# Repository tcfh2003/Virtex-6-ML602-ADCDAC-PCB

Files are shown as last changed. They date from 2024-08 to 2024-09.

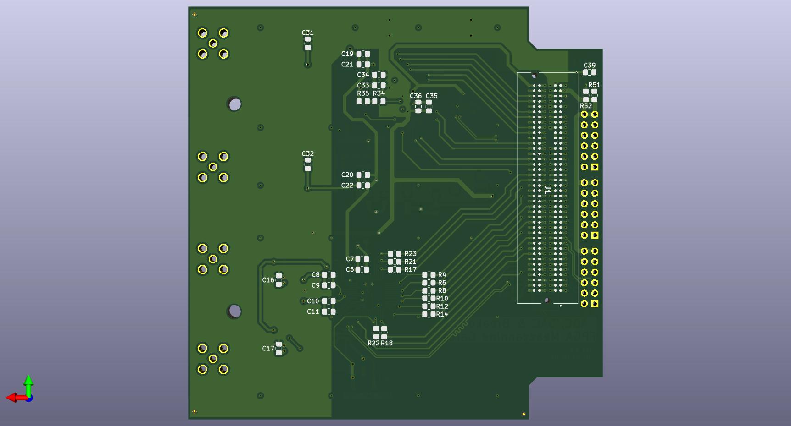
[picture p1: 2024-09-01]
Schematic_and_PCB_Photos/rev1.1/PCB_3DView_BOTTOM_noComponents.png

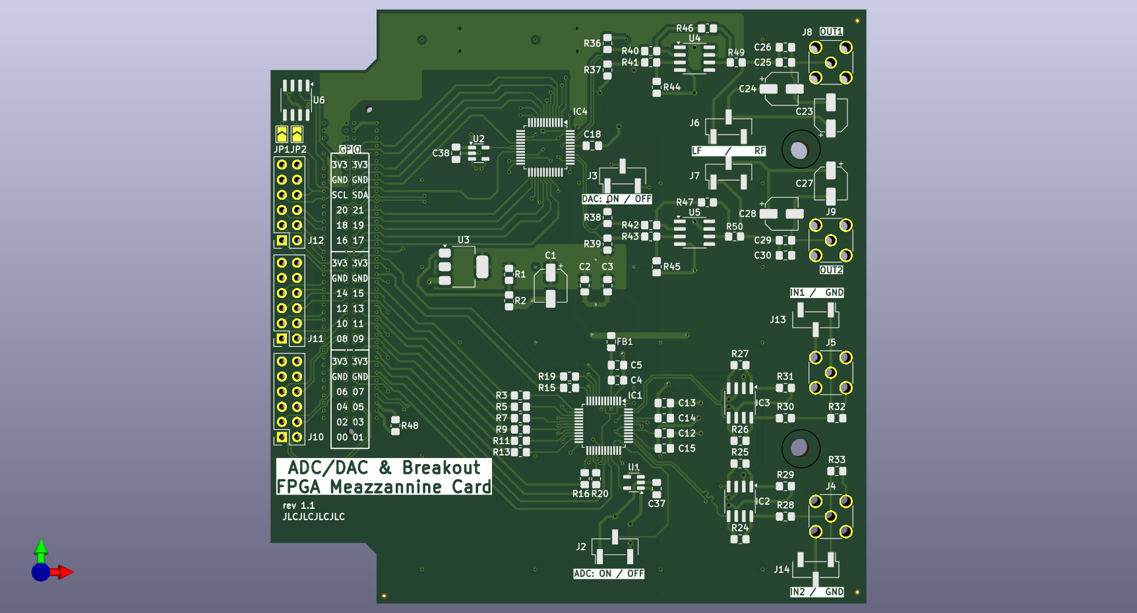
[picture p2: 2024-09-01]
Schematic_and_PCB_Photos/rev1.1/PCB_3DView_TOP_noComponents.png

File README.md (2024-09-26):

# ADC/DAC FPGA Mezannine Card utilizing VITA 57.1 compliant LPC connector.

ADC used is ADC10D040CIVS and has two 10-bit 40 MSa/s channels. DAC used is DAC5652 and has two 10-bit 200 MSa/s channels. 

You can view the PCB online by using https://kicanvas.org (made by theacodes, project github link https://github.com/theacodes/kicanvas.git), and providing the link for the .pro file in this repo.

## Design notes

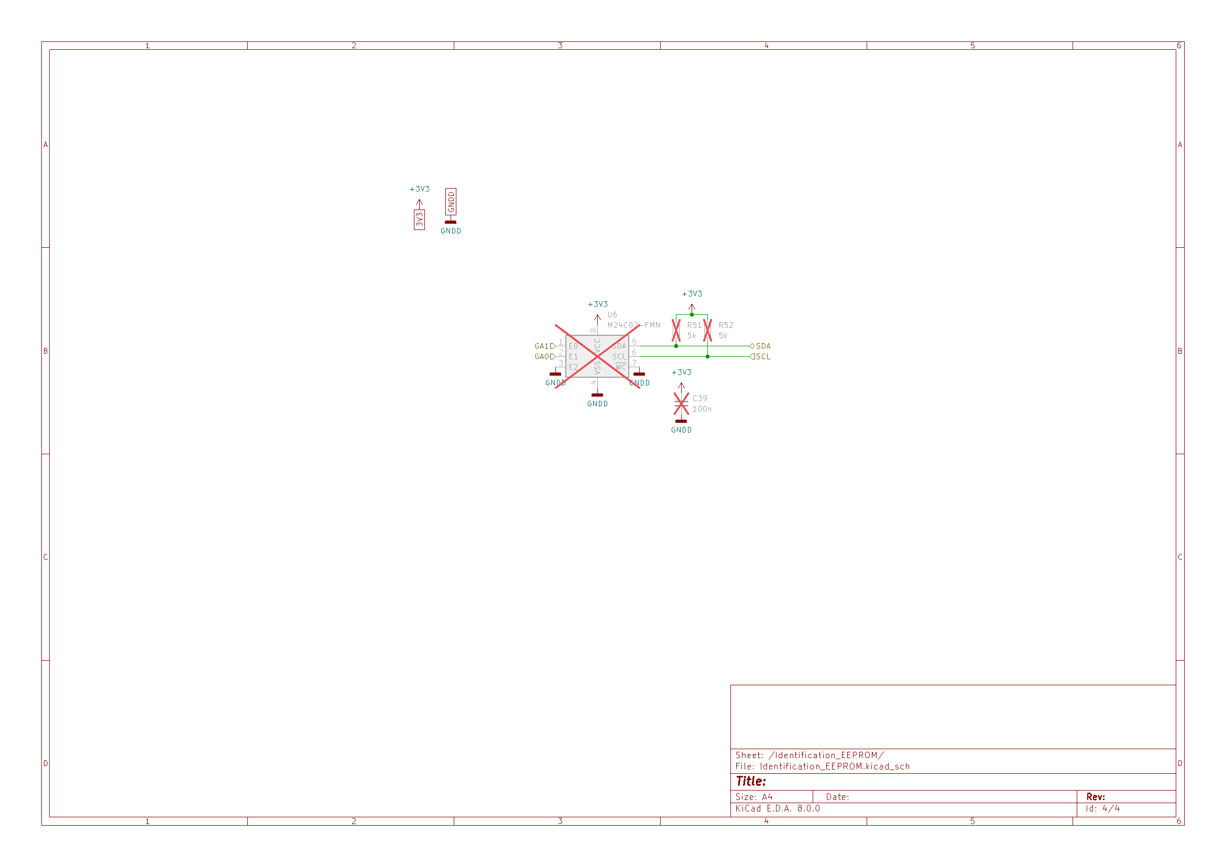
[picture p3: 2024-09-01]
Schematic_and_PCB_Photos/rev1.1/ML605_LPC_Board_wADC_DAC conv 4.png

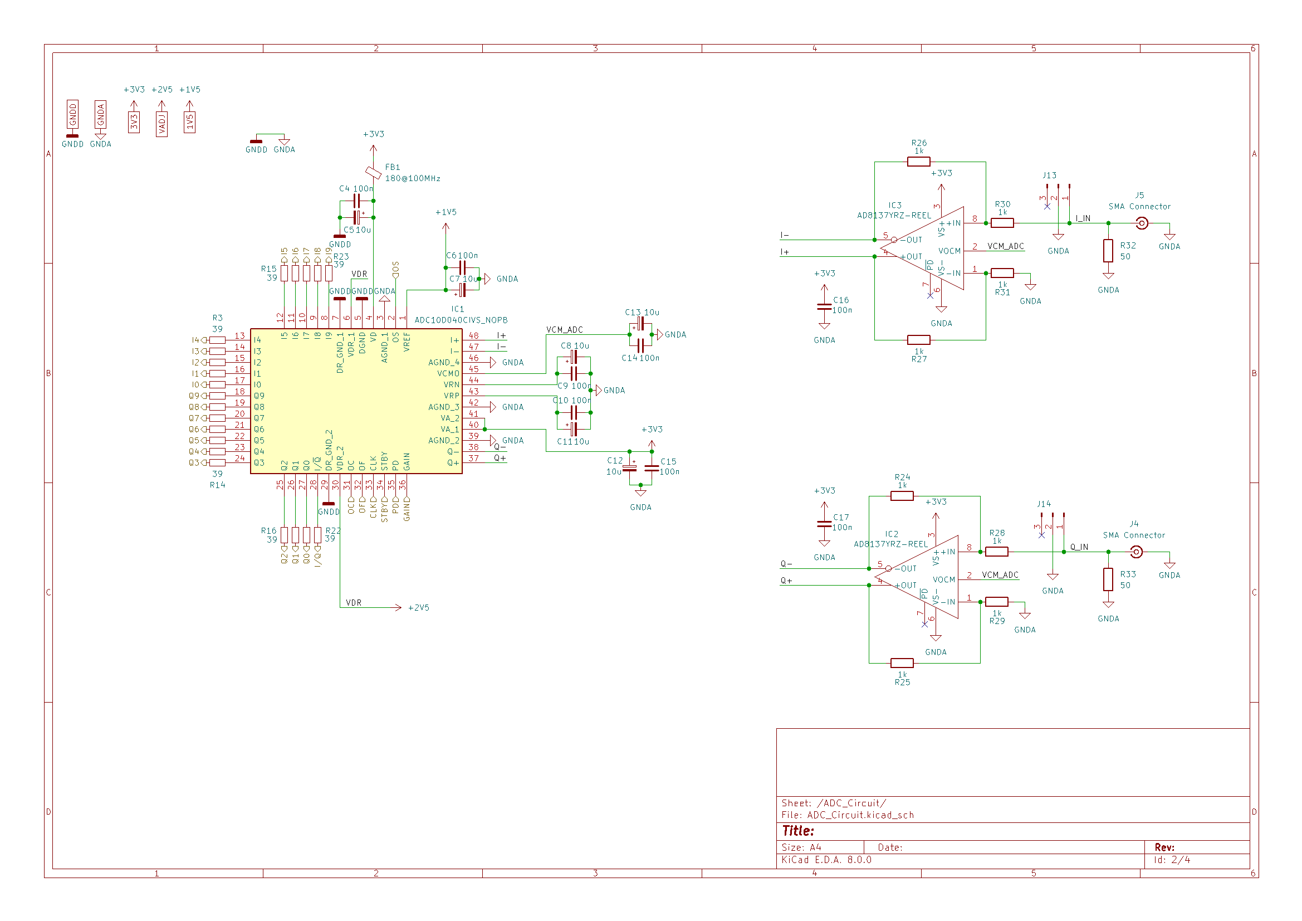
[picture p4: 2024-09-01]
Schematic_and_PCB_Photos/rev1.1/ML605_LPC_Board_wADC_DAC conv 2.png

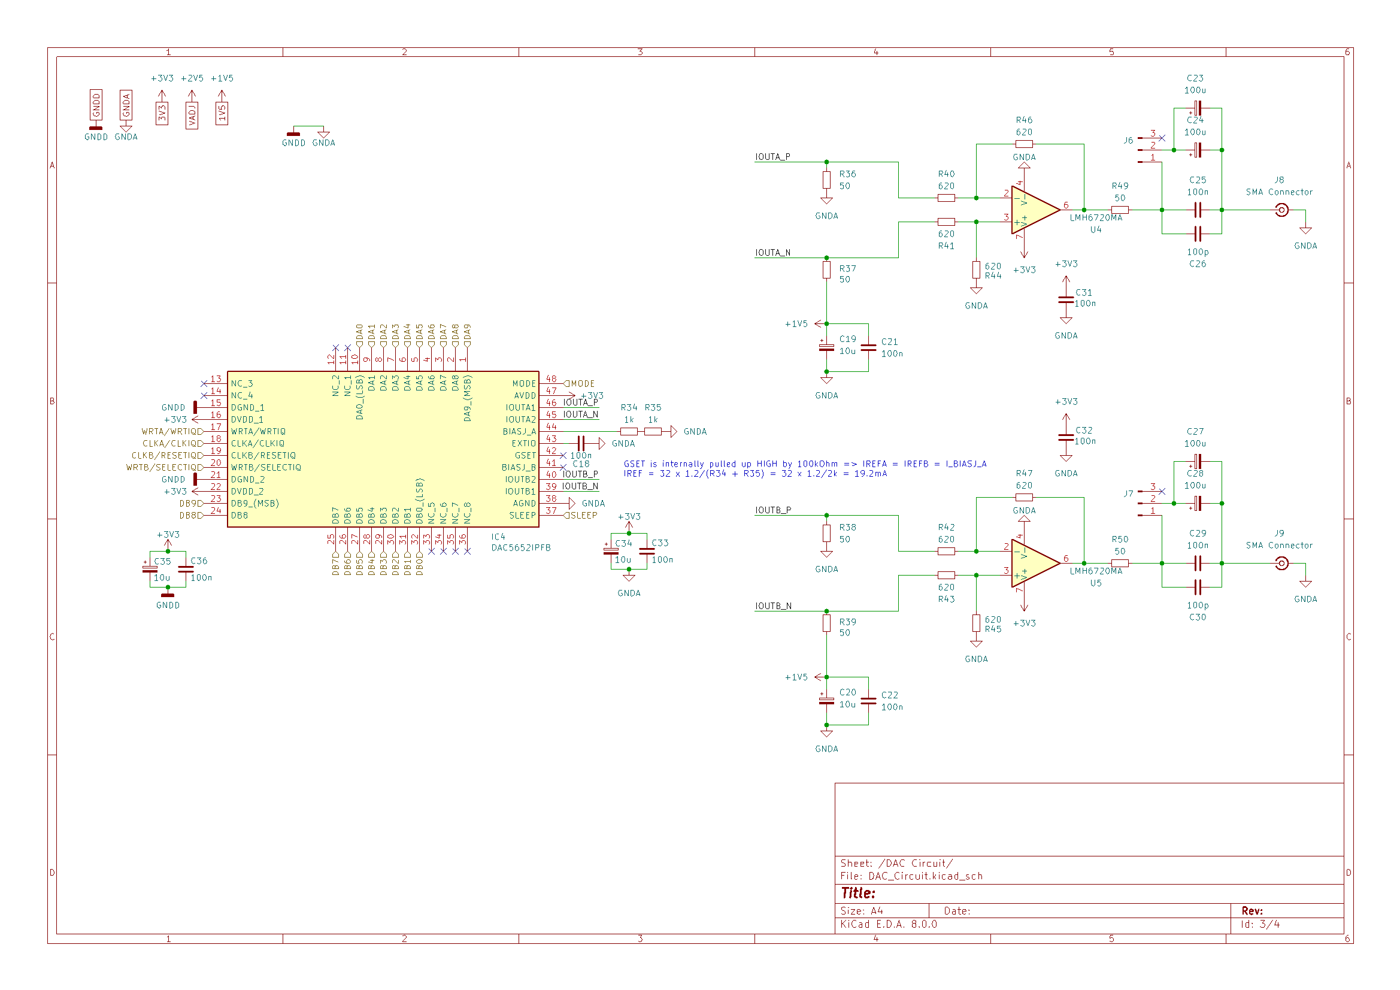
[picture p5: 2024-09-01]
Schematic_and_PCB_Photos/rev1.1/ML605_LPC_Board_wADC_DAC conv 3.png

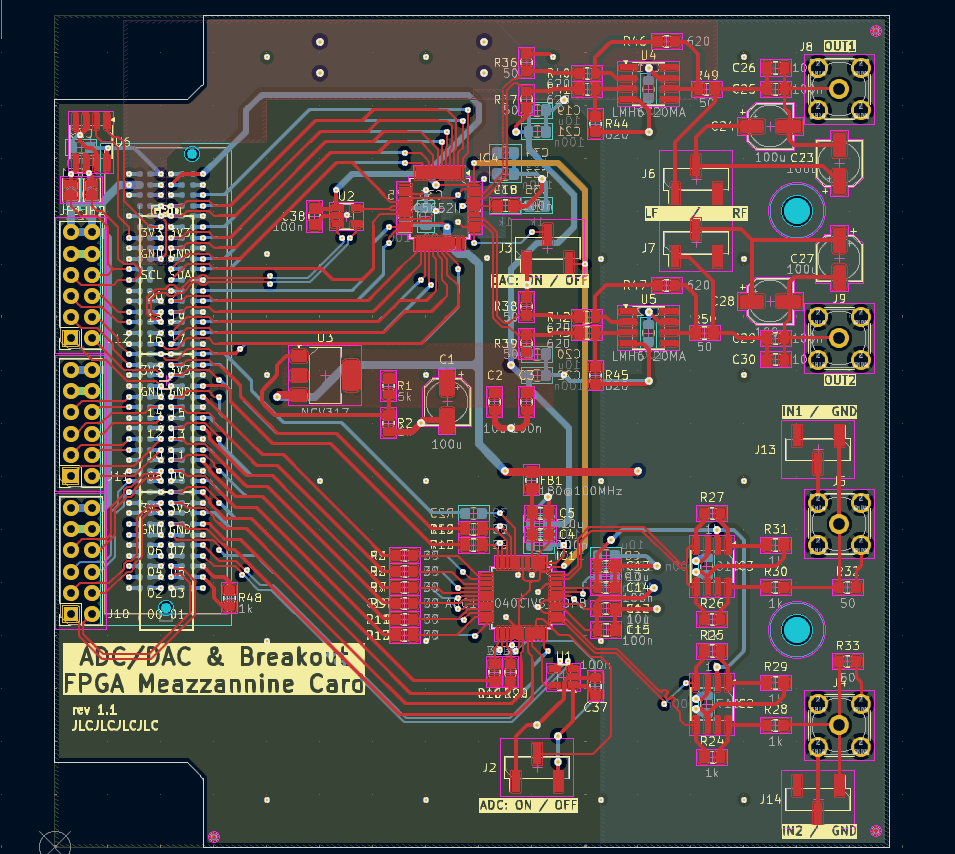
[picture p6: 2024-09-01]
Schematic_and_PCB_Photos/rev1.1/Screenshot 2024-09-01 232856.png

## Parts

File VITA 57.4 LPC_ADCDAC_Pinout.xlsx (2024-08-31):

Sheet: Table 5-1 LPC
4 x 40 | K | J | H | G | F | E | D | C | B | A
1 | X | X | VREF_A_M2C | GND | X | X | PG_C2M | GND | X | X
2 | X | X | PRSNT_M2C_L | CLK1_M2C_P | X | X | GND | DP0_C2M_P | X | X
3 | X | X | GND | CLK1_M2C_N | X | X | GND | DP0_C2M_N | X | X
4 | X | X | CLK0_M2C_P | GND | X | X | GBTCLK0_M2C_P | GND | X | X
5 | X | X | CLK0_M2C_N | GND | X | X | GBTCLK0_M2C_N | GND | X | X
6 | X | X | GND | LA00_P_CC | X | X | GND | DP0_M2C_P | X | X
7 | X | X | LA02_P | LA00_N_CC | X | X | GND | DP0_M2C_N | X | X
8 | X | X | LA02_N | GND | X | X | LA01_P_CC | GND | X | X
9 | X | X | GND | LA03_P | X | X | LA01_N_CC | GND | X | X
10 | X | X | LA04_P | LA03_N | X | X | GND | LA06_P | X | X
11 | X | X | LA04_N | GND | X | X | LA05_P | LA06_N | X | X
12 | X | X | GND | LA08_P | X | X | LA05_N | GND | X | X
13 | X | X | LA07_P | LA08_N | X | X | GND | GND | X | X
14 | X | X | LA07_N | GND | X | X | LA09_P | LA10_P | X | X
15 | X | X | GND | LA12_P | X | X | LA09_N | LA10_N | X | X
16 | X | X | LA11_P | LA12_N | X | X | GND | GND | X | X
17 | X | X | LA11_N | GND | X | X | LA13_P | GND | X | X
18 | X | X | GND | LA16_P | X | X | LA13_N | LA14_P | X | X
19 | X | X | LA15_P | LA16_N | X | X | GND | LA14_N | X | X
20 | X | X | LA15_N | GND | X | X | LA17_P_CC | GND | X | X
21 | X | X | GND | LA20_P | X | X | LA17_N_CC | GND | X | X
22 | X | X | LA19_P | LA20_N | X | X | GND | LA18_P_CC | X | X
23 | X | X | LA19_N | GND | X | X | LA23_P | LA18_N_CC | X | X
24 | X | X | GND | LA22_P | X | X | LA23_N | GND | X | X
25 | X | X | LA21_P | LA22_N | X | X | GND | GND | X | X
26 | X | X | LA21_N | GND | X | X | LA26_P | LA27_P | X | X
27 | X | X | GND | LA25_P | X | X | LA26_N | LA27_N | X | X
28 | X | X | LA24_P | LA25_N | X | X | GND | GND | X | X
29 | X | X | LA24_N | GND | X | X | TCK | GND | X | X
30 | X | X | GND | LA29_P | X | X | TDI | SCL | X | X
31 | X | X | LA28_P | LA29_N | X | X | TDO | SDA | X | X
32 | X | X | LA28_N | GND | X | X | 3P3VAUX | GND | X | X
33 | X | X | GND | LA31_P | X | X | TMS | GND | X | X
34 | X | X | LA30_P | LA31_N | X | X | TRST_L | GA0 | X | X
35 | X | X | LA30_N | GND | X | X | GA1 | 12P0V | X | X
36 | X | X | GND | LA33_P | X | X | 3P3V | GND | X | X
37 | X | X | LA32_P | LA33_N | X | X | GND | 12P0V | X | X
38 | X | X | LA32_N | GND | X | X | 3P3V | GND | X | X
39 | X | X | GND | VADJ | X | X | GND | 3P3V | X | X
40 | X | X | VADJ | GND | X | X | 3P3V | GND | X | X

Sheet: Table 5-1 LPC ADC|DAC Pinout
4 x 40 | K | J | H | G | F | E | D | C | B | A
1 | X | X | NC | GND | X | X | NC | GND | X | X
2 | X | X | PRSNT_M2C_L (GPIO) | GPIO0 | X | X | GND | MGT_TX0_P (NC) | X | X
3 | X | X | GND | GPIO1 | X | X | GND | MGT_TX0_N (NC) | X | X
4 | X | X | ADC_CLK_P (40MHz) | GND | X | X | GBTCLK0_RX_P (NC) | GND | X | X
5 | X | X | ADC_CLK_N (40MHz) | GND | X | X | GBTCLK0_RX_N (NC) | GND | X | X
6 | X | X | GND | ADC_GAIN | X | X | GND | MGT_RX0_P (NC) | X | X
7 | X | X | ADC_OC | ADC_OF | X | X | GND | MGT_RX0_N (NC) | X | X
8 | X | X | ADC_IQ* | GND | X | X | GPIO2 | GND | X | X
9 | X | X | GND | ADC_Q0 | X | X | GPIO3 | GND | X | X
10 | X | X | ADC_Q2 | ADC_Q1 | X | X | GND | GPIO4 | X | X
11 | X | X | ADC_Q3 | GND | X | X | GPIO6 | GPIO5 | X | X
12 | X | X | GND | ADC_Q4 | X | X | GPIO7 | GND | X | X
13 | X | X | ADC_Q6 | ADC_Q5 | X | X | GND | GND | X | X
14 | X | X | ADC_Q7 | GND | X | X | GPIO8 | GPIO10 | X | X
15 | X | X | GND | ADC_Q8 | X | X | GPIO9 | GPIO11 | X | X
16 | X | X | ADC_I0 | ADC_Q9 | X | X | GND | GND | X | X
17 | X | X | ADC_I1 | GND | X | X | GPIO12 | GND | X | X
18 | X | X | GND | ADC_I2 | X | X | GPIO13 | GPIO14 | X | X
19 | X | X | ADC_I4 | ADC_I3 | X | X | GND | GPIO15 | X | X
20 | X | X | ADC_I5 | GND | X | X | GPIO16 | GND | X | X
21 | X | X | GND | ADC_I6 | X | X | GPIO17 | GND | X | X
22 | X | X | ADC_I8 | ADC_I7 | X | X | GND | GPIO18 | X | X
23 | X | X | ADC_I9 | GND | X | X | DAC_DB0 | GPIO19 | X | X
24 | X | X | GND | DAC_DB2 | X | X | DAC_DB1 | GND | X | X
25 | X | X | DAC_DB4 | DAC_DB3 | X | X | GND | GND | X | X
26 | X | X | DAC_DB5 | GND | X | X | DAC_CLK_P (200MHz) | GPIO20 | X | X
27 | X | X | GND | DAC_DB6 | X | X | DAC_CLK_N (200MHz) | GPIO21 | X | X
28 | X | X | DAC_DB8 | DAC_DB7 | X | X | GND | GND | X | X
29 | X | X | DAC_DB9 | GND | X | X | NC | GND | X | X
30 | X | X | GND | DAC_WRTB | X | X | NC | SCL/GPIO | X | X
31 | X | X | DAC_DA0 | DAC_WRTA | X | X | NC | SDA/GPIO | X | X
32 | X | X | DAC_DA1 | GND | X | X | 3P3VAUX | GND | X | X
33 | X | X | GND | DAC_DA2 | X | X | NC | GND | X | X
34 | X | X | DAC_DA4 | DAC_DA3 | X | X | NC | GA0 = GND | X | X
35 | X | X | DAC_DA5 | GND | X | X | GA1 = 3V3 | 12P0V | X | X
36 | X | X | GND | DAC_DA6 | X | X | 3P3V | GND | X | X
37 | X | X | DAC_DA8 | DAC_DB7 | X | X | GND | 12P0V | X | X
38 | X | X | DAC_DA9 | GND | X | X | 3P3V | GND | X | X
39 | X | X | GND | VADJ | X | X | GND | 3P3V | X | X
40 | X | X | VADJ | GND | X | X | 3P3V | GND | X | X
 |  |  |  |  |  | Notes:
 |  |  |  |  |  | C30 (SCL) & C31 (SDA) are > 2.5V tolerant, but need a 2k pullup on mezannine board (there's a mosfet level shifter there)

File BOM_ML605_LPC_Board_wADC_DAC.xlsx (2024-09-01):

Reference | Value | Mouser Link | Qty | DNP | Mouser Code | Mouser Unit Price | Mouser Total Price
C1,C23,C24,C27,C28 | 100u | https://ro.mouser.com/ProductDetail/Wurth-Elektronik/865080142007 | 5 |  | 710-865080142007 | 0.693 | 6.93
C2,C5,C7,C8,C11,C12,C13,C19,C20,C34,C35 | 10u | https://ro.mouser.com/ProductDetail/Samsung-Electro-Mechanics/CL21A106KOQNNNE | 11 |  | 187-CL21A106KOQNNNE | 0.178 | 2.67
C3,C4,C6,C9,C10,C14,C15,C16,C17,C18,C21,C22,C25,C29,C31,C32,C33,C36,C37,C38 | 100n | https://ro.mouser.com/ProductDetail/KEMET/C0805C104Z5VACTU | 20 |  | 80-C0805C104Z5V | 0.109 | 2.725
C26,C30 | 100p | https://ro.mouser.com/ProductDetail/Wurth-Elektronik/885012007034 | 2 |  | 710-885012007034 | 0.46 | 0.92
U4,U5 | LMH6720MA | https://ro.mouser.com/ProductDetail/Texas-Instruments/LMH6720MA-NOPB?qs=7lkVKPoqpbYEx%252BsV5%252BDiyQ%3D%3D | 2 |  | 926-LMH6720MA/NOPB | 10.54 | 21.08
U3 | NCV317 | https://ro.mouser.com/ProductDetail/onsemi/NCV317MBSTT3G?qs=3PKVEWFFm2%252BSS0n2wMgniA%3D%3D | 1 |  | 863-NCV317MBSTT3G | 1.98 | 1.98
U1,U2 | SN65LVDS2DBVR | https://ro.mouser.com/ProductDetail/Texas-Instruments/SN65LVDS2DBVR?qs=0le1rQK8zxoNN%2Fzey0Z7qg%3D%3D | 2 |  | 595-SN65LVDS2DBVR | 7.13 | 14.26
R40,R41,R42,R43,R44,R45,R46,R47 | 620 | https://ro.mouser.com/ProductDetail/Kamaya/RMC1-10-621JTP | 8 |  | 791-RMC1/10-621JTP | 0.084 | 0.84
R32,R33,R36,R37,R38,R39 | 50 | https://ro.mouser.com/ProductDetail/Vishay-Dale/CRCW080550R0FKTA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 | 8 |  | 71-CRCW0805-50 | 0.941 | 9.41
R3,R4,R5,R6,R7,R8,R9,R10,R11,R12,R13,R14,R15,R16,R17,R18,R19,R20,R21,R22,R23 | 39 | https://ro.mouser.com/ProductDetail/Susumu/RR1220Q-39R2-D-M | 21 |  | 754-RR1220Q-39R2D-M | 0.262 | 6.55
R2,R24,R25,R26,R27,R28,R29,R30,R31,R34,R35,R48 | 1k | https://ro.mouser.com/ProductDetail/YAGEO/AC0805JR-071KL | 12 |  | 603-AC0805JR-071KL | 0.079 | 1.185
R1 | 5k | https://ro.mouser.com/ProductDetail/SEI-Stackpole/RMCF0805FT4K99 | 1 |  | 708-RMCF0805FT4K99 | 0.46 | 0.46
FB1 | 470@100MHz | https://ro.mouser.com/ProductDetail/Bourns/MH2029-471Y?qs=aqFbwuCjQoliK9N17aAXAA%3D%3D | 1 |  | 652-MH2029-471Y | 0.46 | 0.46
J10,J11,J12 | Conn_02x06_Odd_Even | https://ro.mouser.com/ProductDetail/Samtec/SSW-106-01-T-D?qs=iT52DjcXuds3ZRKSeKutcw%3D%3D | 3 |  | 200-SSW10601TD | 5.59 | 16.77
J4,J5,J8,J9 | SMA Connector | https://ro.mouser.com/ProductDetail/LPRS/SMA-CONNECTOR?qs=j%252B1pi9TdxUYkOiITvzJM8A%3D%3D | 4 |  | 471-SMACONNECTOR | 8.51 | 34.04
J2,J3,J6,J7,J13,J14 | Conn_01x03_Pin | https://ro.mouser.com/ProductDetail/Amphenol-FCI/10129380-903001BLF?qs=0lQeLiL1qyY7ch20dCKSWg%3D%3D | 6 |  | 649-1012938090301BLF | 0.371 | 3.71
J1 | ASP-134604-01 | https://ro.mouser.com/ProductDetail/Samtec/ASP-134604-01?qs=Rp%2FUEJiACm00i8g2mQ6XNw%3D%3D | 1 |  | 200-ASP-134604-01 | 95.73 | 95.73
IC4 | DAC5652IPFB | https://ro.mouser.com/ProductDetail/Texas-Instruments/DAC5652IPFB?qs=vul0MlC%2Fa1cvaqYYgQzY1A%3D%3D | 1 |  | 595-DAC5652IPFB | 62.27 | 62.27
IC2,IC3 | AD8137YRZ-REEL | https://ro.mouser.com/ProductDetail/Analog-Devices/AD8137YRZ-REEL?qs=%2FtpEQrCGXCwvx9BEhEk72g%3D%3D | 2 |  | 584-AD8137YRZ-R | 15.39 | 30.78
IC1 | ADC10D040CIVS_NOPB | https://ro.mouser.com/ProductDetail/Texas-Instruments/ADC10D040CIVS-NOPB?qs=7X5t%252BdzoRHCI2Z2wyV07LA%3D%3D | 1 |  | 926-ADC10D040CIVSNPB | 63.36 | 63.36
 |  |  |  |  |  | TOTAL PRICE (no VAT) : | 376.13
 |  |  |  |  |  | VAT (in Czech Republic): | 21%
 |  |  |  |  |  | TOTAL PRICE (with VAT): | 455.1173

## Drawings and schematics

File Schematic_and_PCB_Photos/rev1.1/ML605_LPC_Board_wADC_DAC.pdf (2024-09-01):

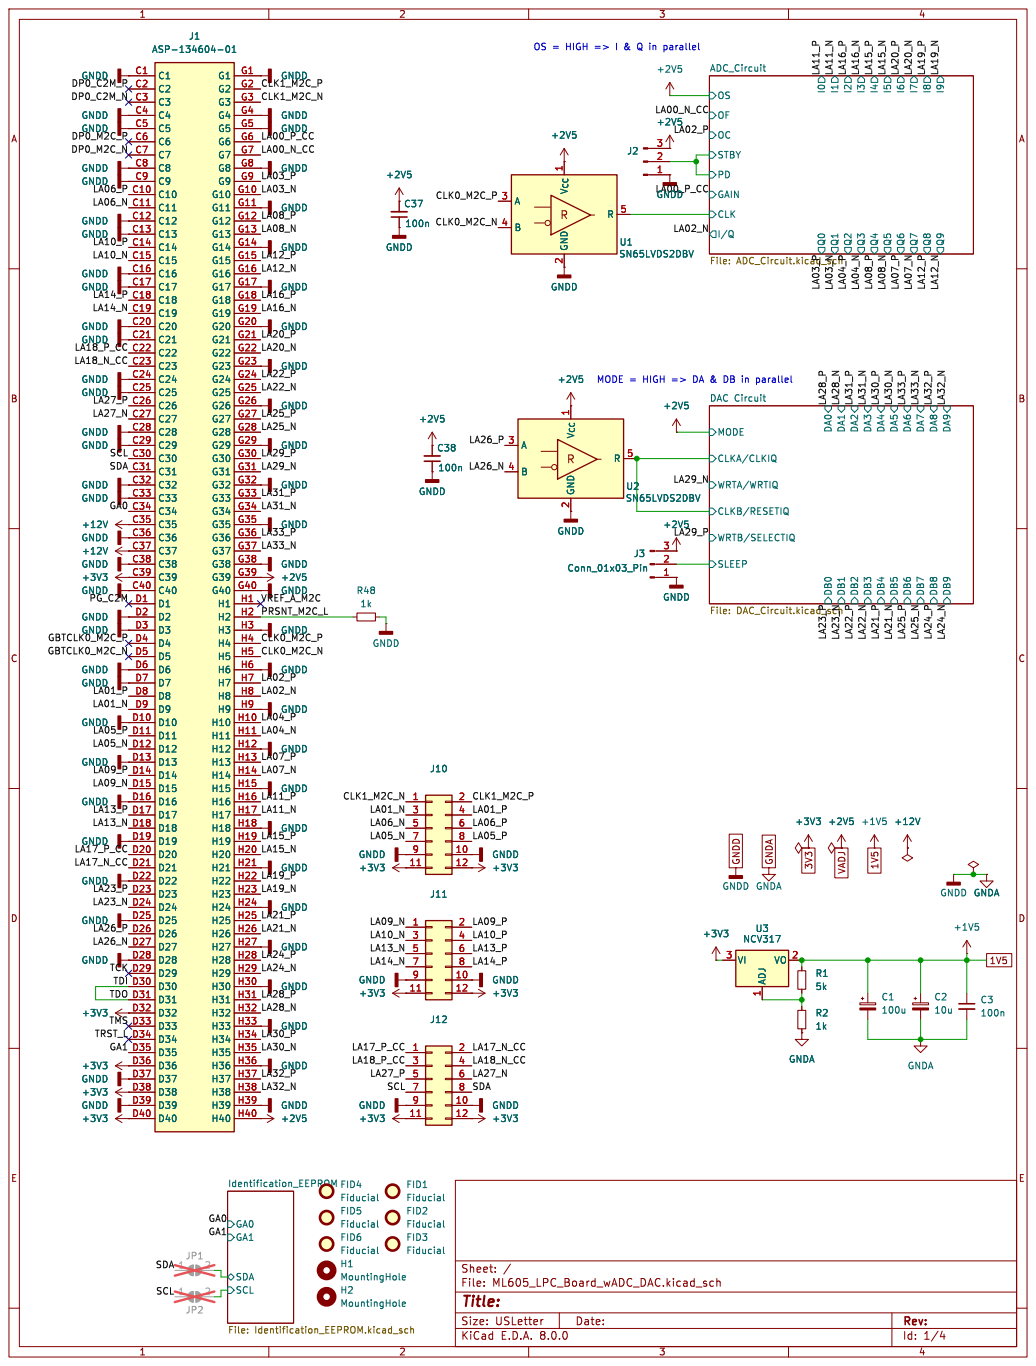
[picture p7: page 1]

+2V5 GNDD GNDD GNDD GNDD GNDD GNDD GNDD

Id: 1/4 Title: File: ML605_LPC_Board_wADC_DAC.kicad_sch Sheet: /

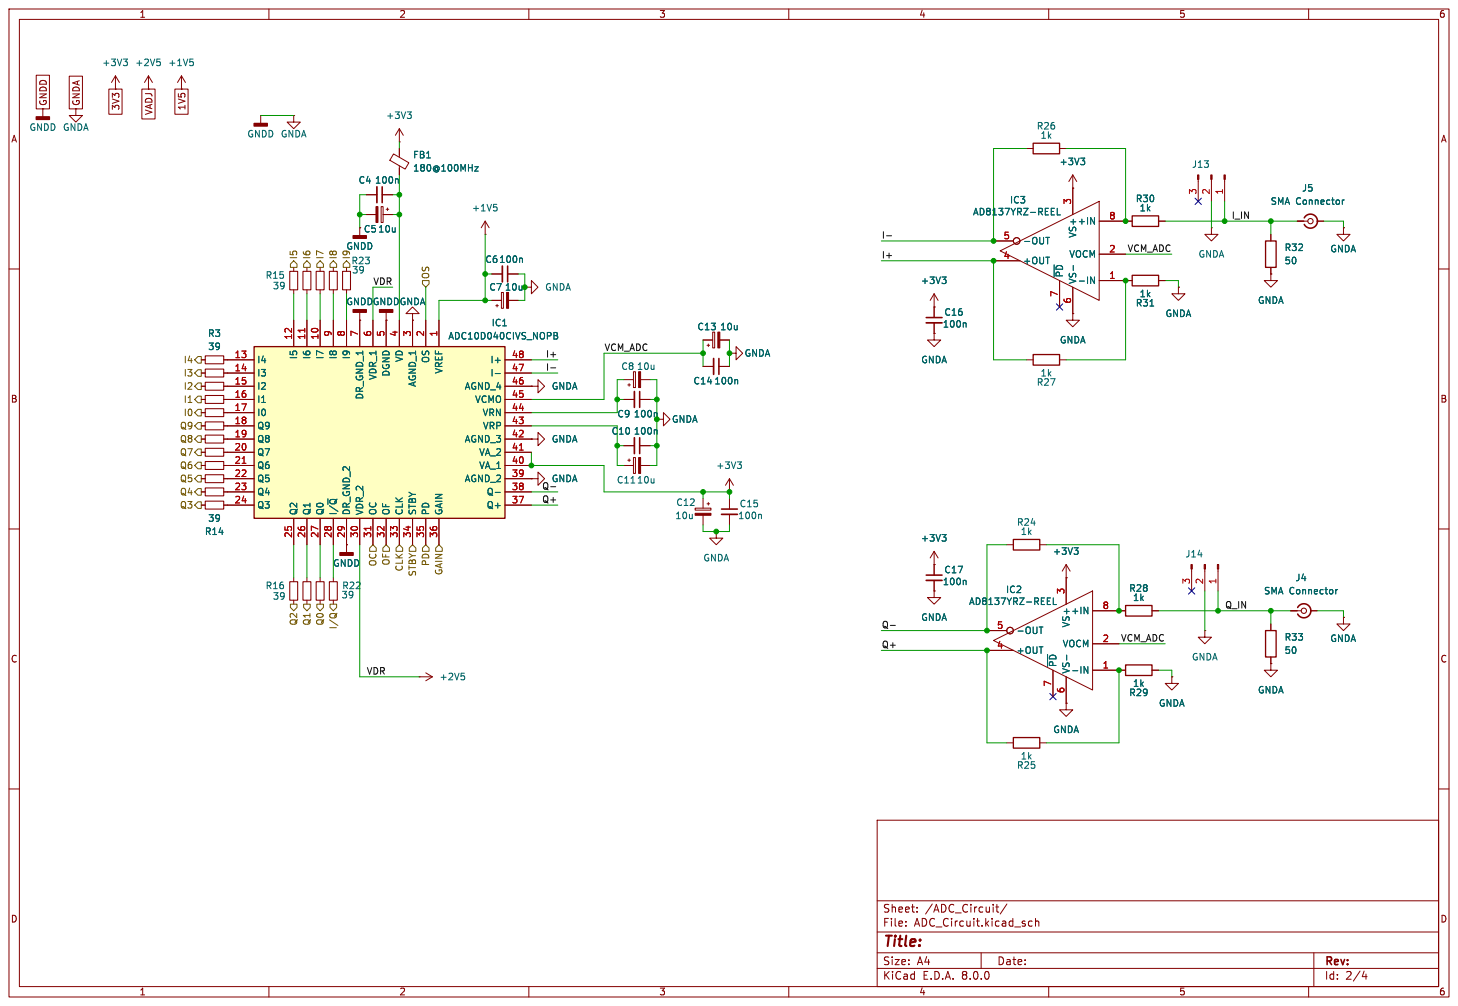
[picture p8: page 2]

3 VDR_2 30 OC 31 OF 32 CLK 33 STBY 34 PD 35 GAIN 36 Q+ 37 Q- 38 AGND_2 39 VD

Id: 2/4 Title: File: ADC_Circuit.kicad_sch Sheet: /ADC_Circuit/

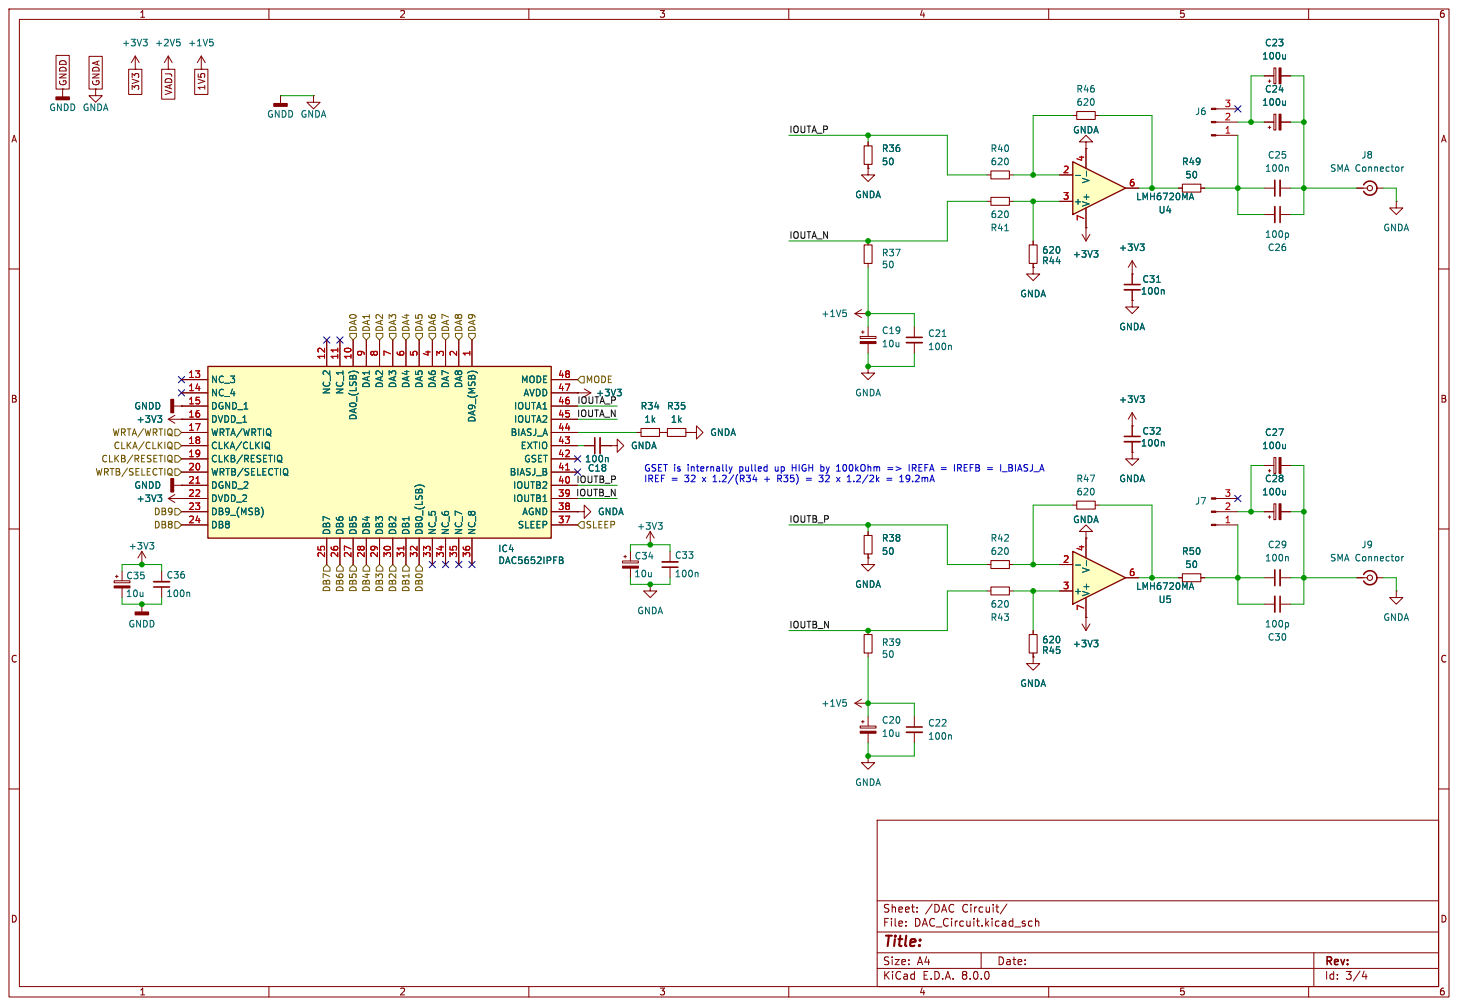
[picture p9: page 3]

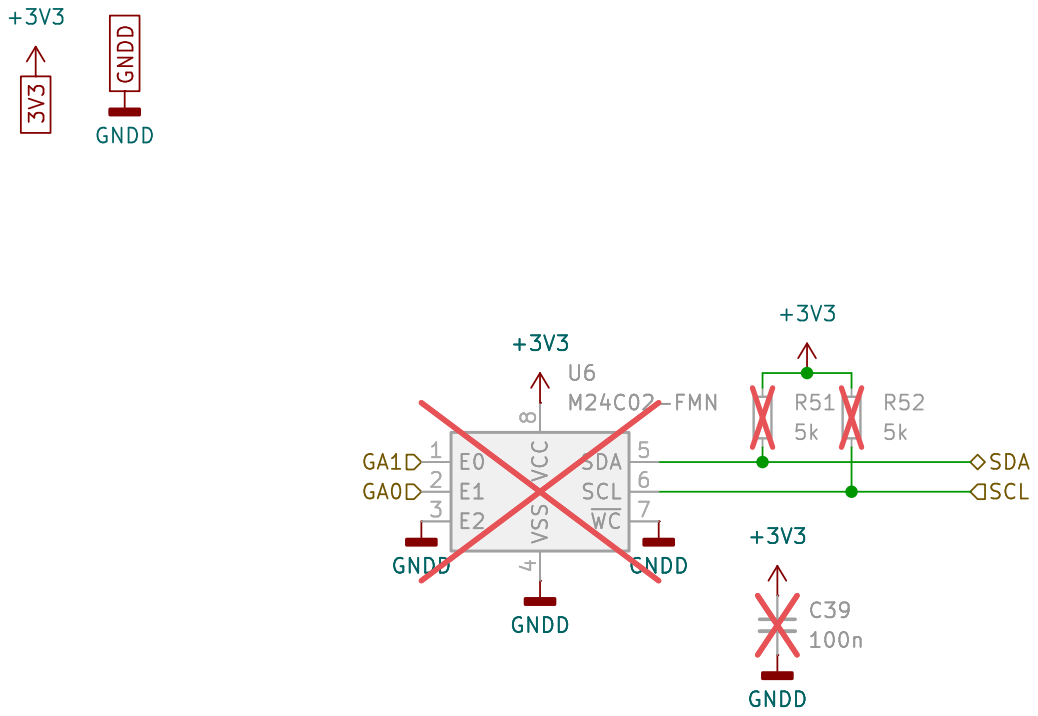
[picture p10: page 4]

4 SDA 5 SCL 6 ~{WC}7 VCC

Id: 4/4 Title: File: Identification_EEPROM.kicad_sch Sheet: /Identification_EEPROM/

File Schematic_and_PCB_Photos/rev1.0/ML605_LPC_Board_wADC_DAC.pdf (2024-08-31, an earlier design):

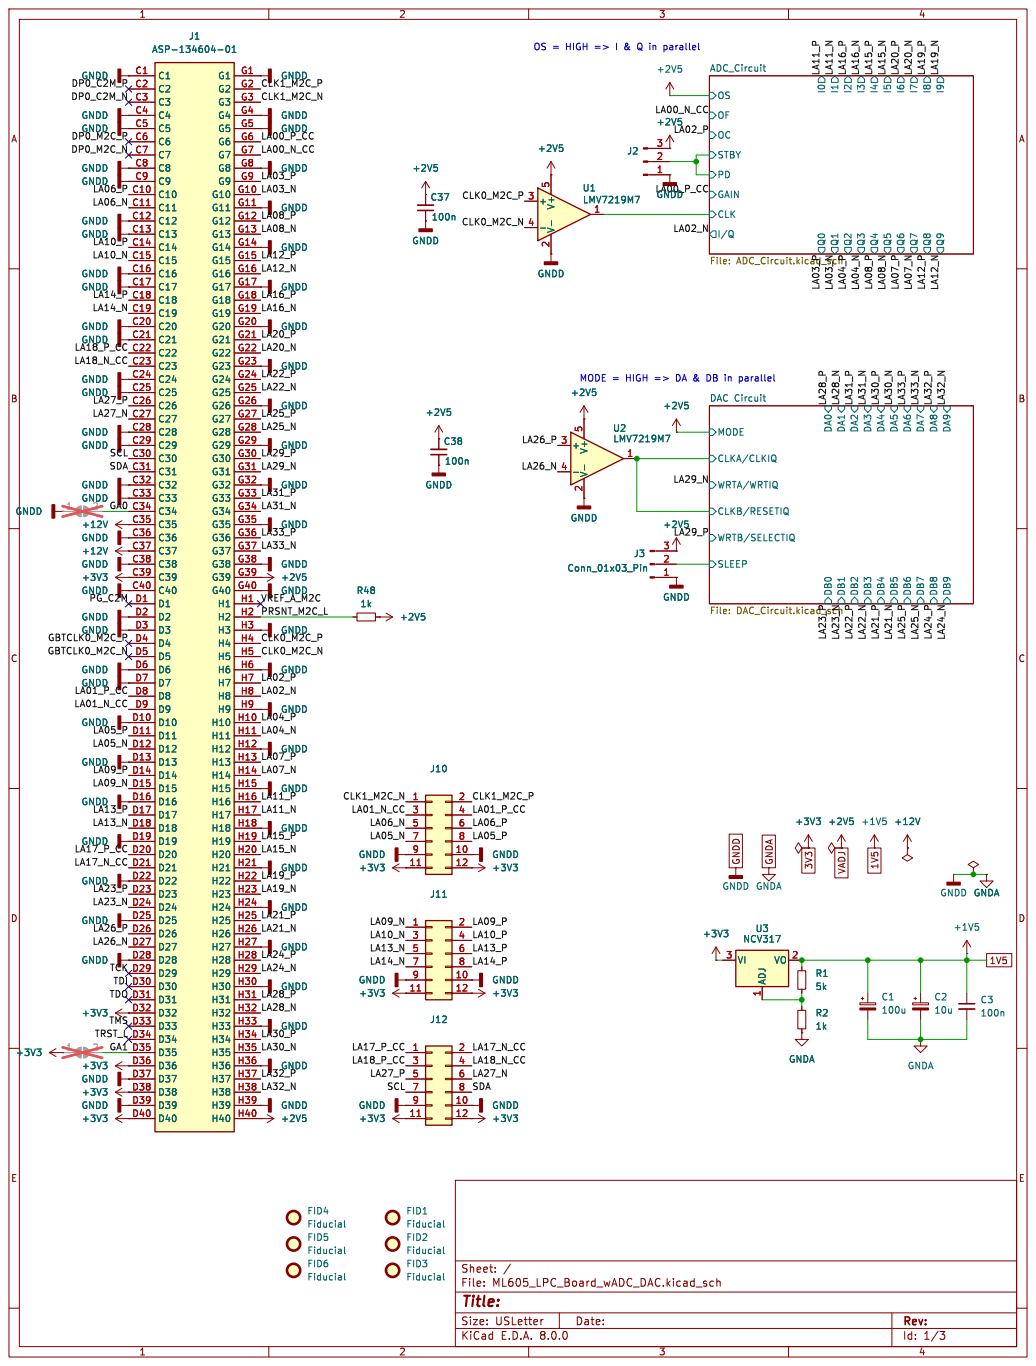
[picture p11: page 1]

GNDD GNDD GNDD

1k GNDD GNDD GNDD GNDD

Id: 1/3 Title: File: ML605_LPC_Board_wADC_DAC.kicad_sch Sheet: /

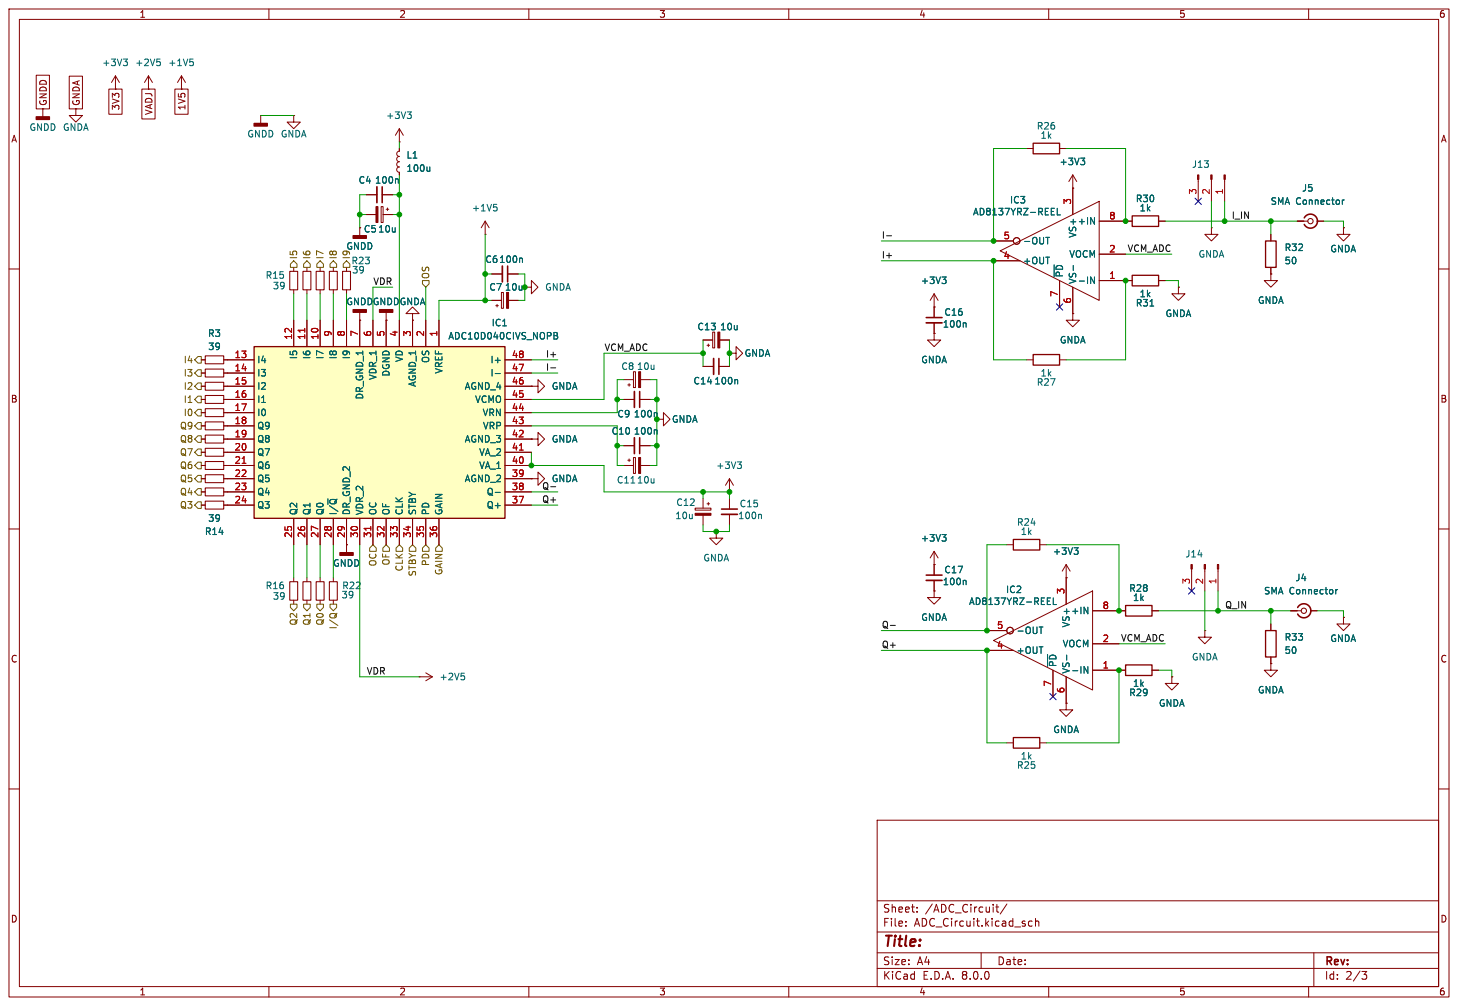
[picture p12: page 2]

3 VDR_2 30 OC 31 OF 32 CLK 33 STBY 34 PD 35 GAIN 36 Q+ 37 Q- 38 AGND_2 39 VD

Id: 2/3 Title: File: ADC_Circuit.kicad_sch Sheet: /ADC_Circuit/

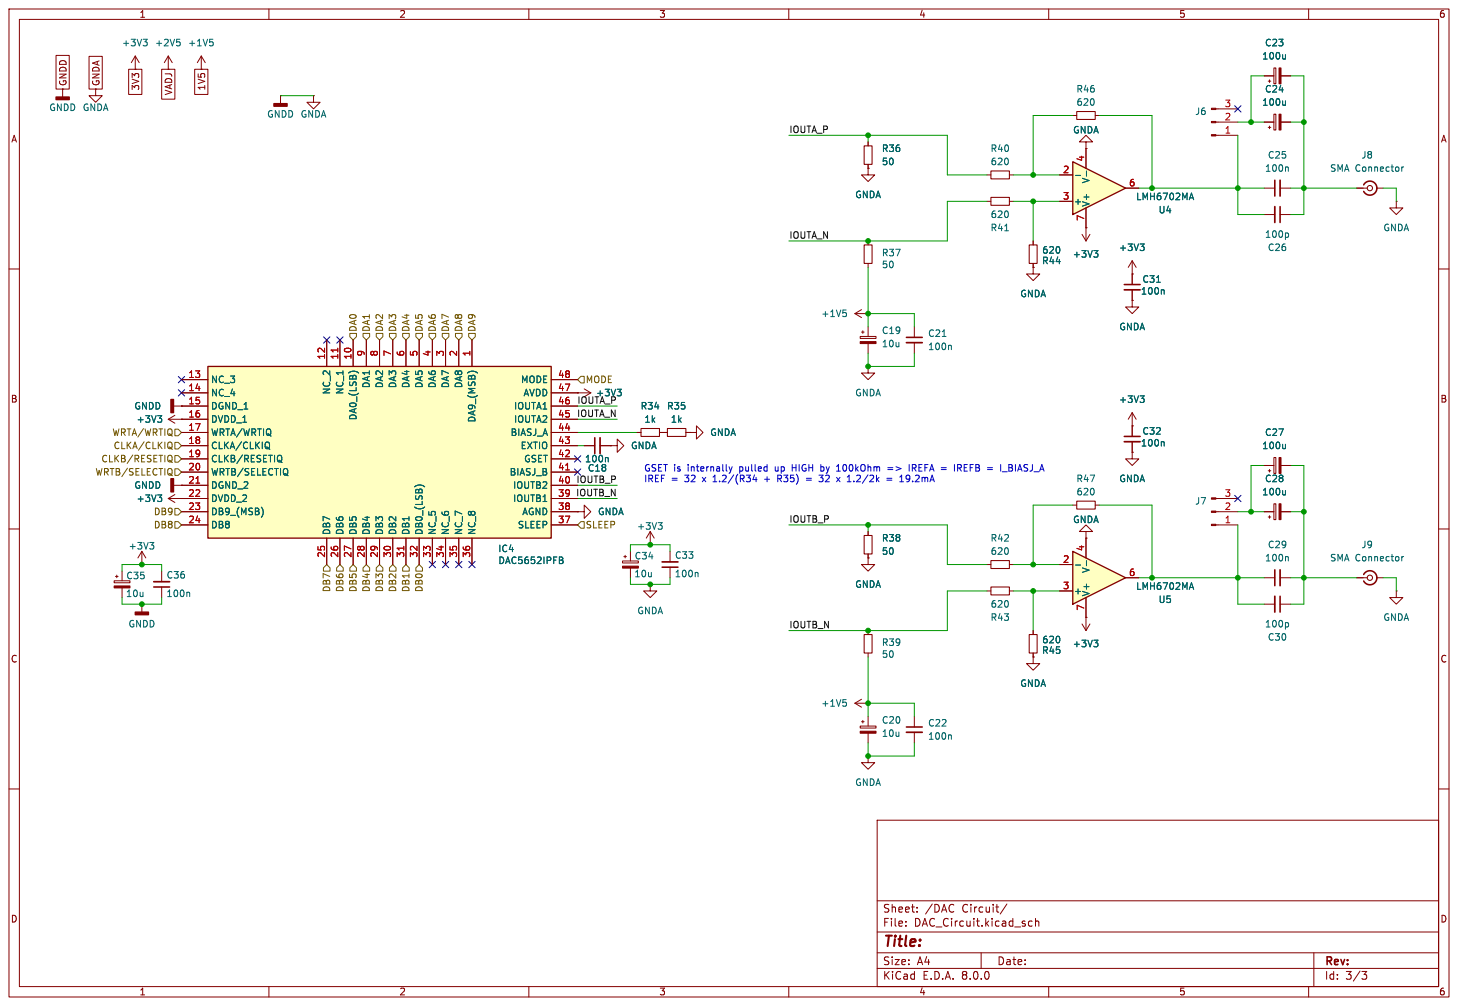
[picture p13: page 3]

Id: 3/3 Title: File: DAC_Circuit.kicad_sch Sheet: /DAC Circuit/ GNDA

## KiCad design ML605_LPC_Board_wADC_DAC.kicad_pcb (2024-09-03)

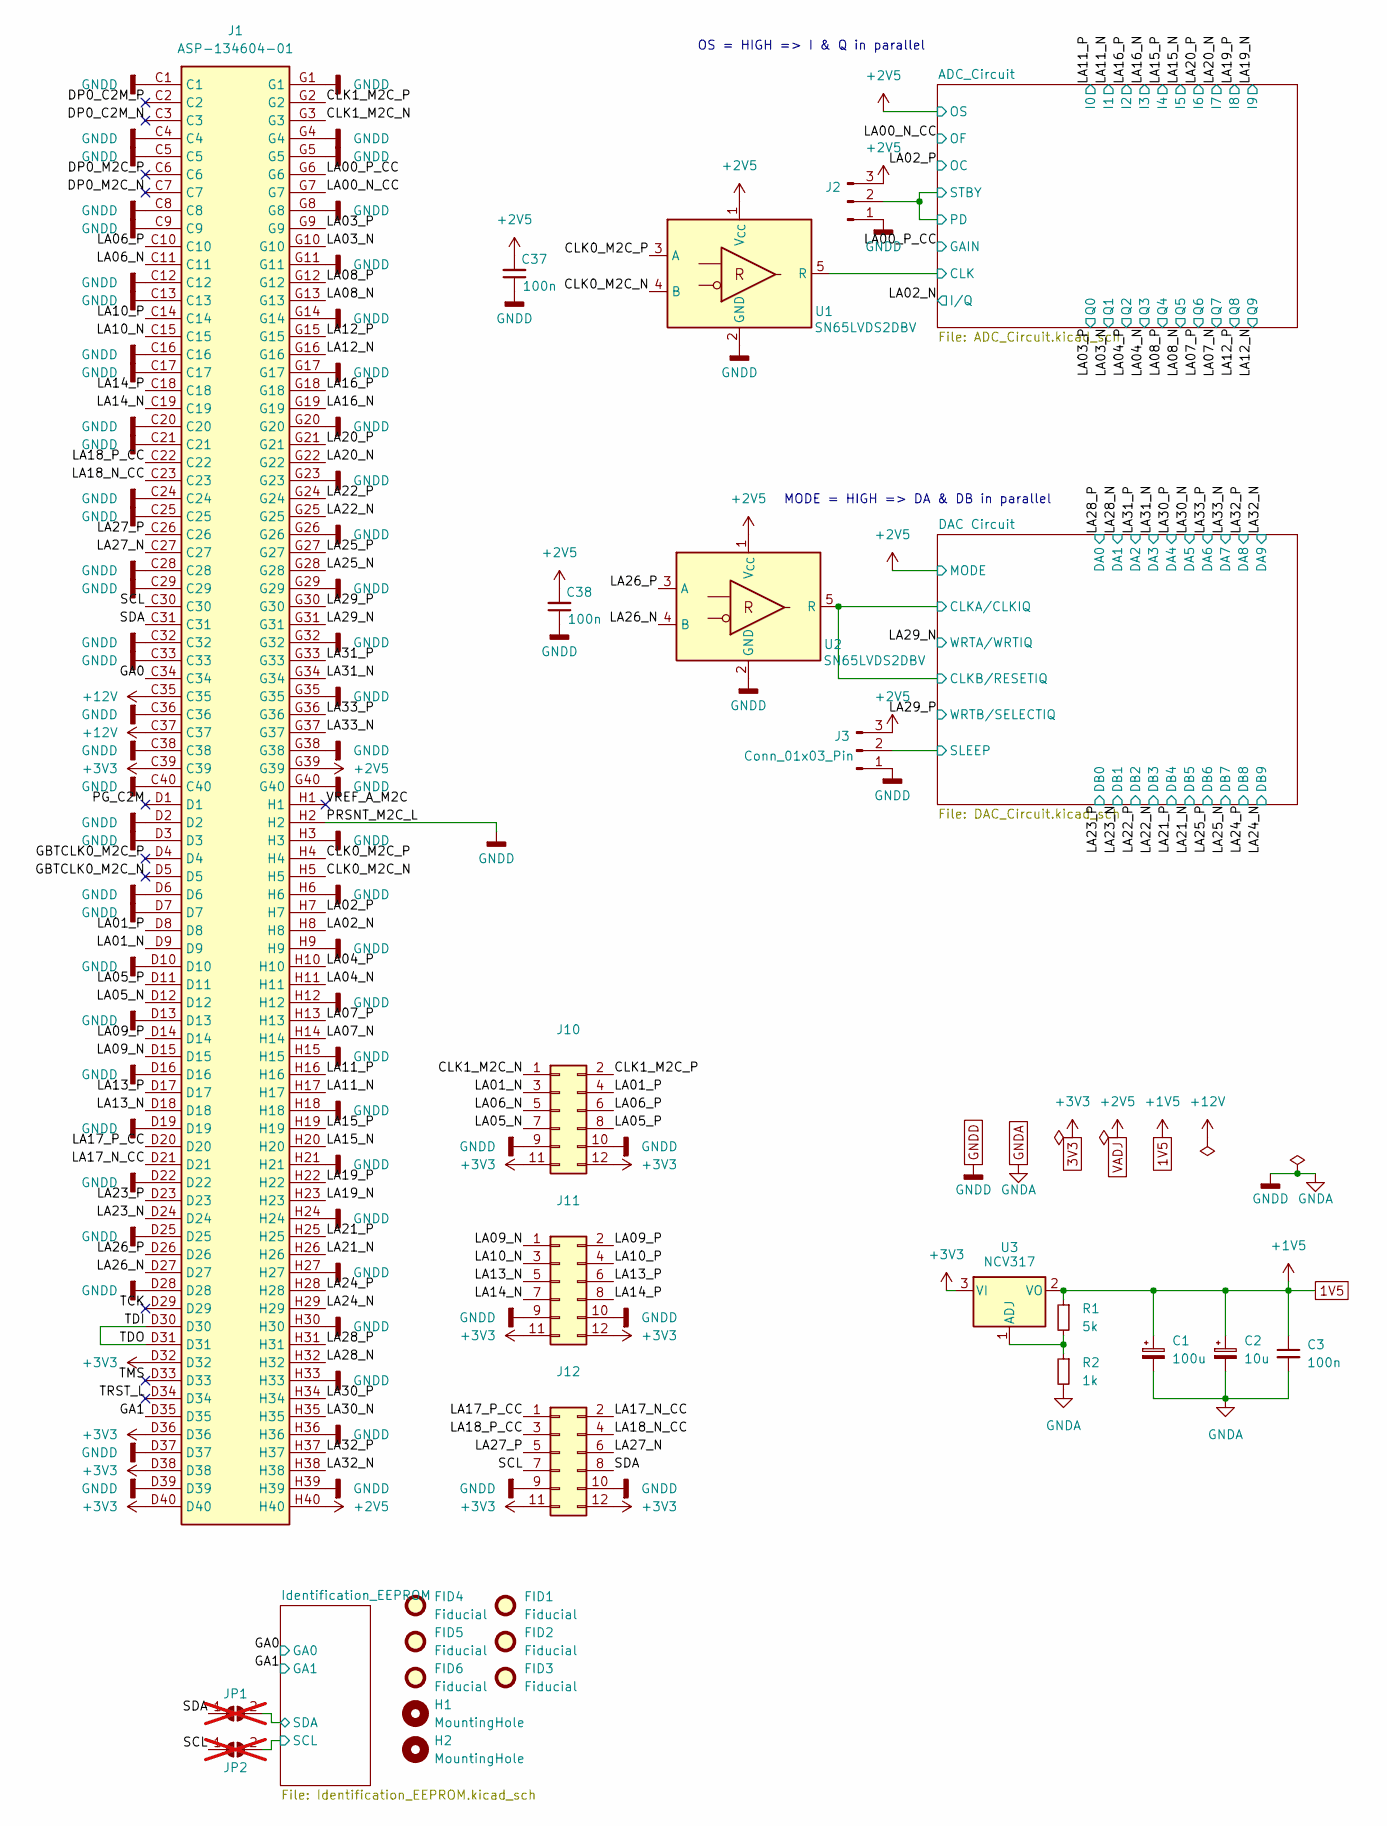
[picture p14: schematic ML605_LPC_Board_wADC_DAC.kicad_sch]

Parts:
C1: 100u; CP_Elec_5x5.3; LCSC C15008 (MLCC 1206)
C2: 10u; C_0805_2012Metric_Pad1.18x1.45mm_HandSolder; LCSC C408141
C3, C37, C38: 100n; C_0805_2012Metric_Pad1.18x1.45mm_HandSolder; LCSC C49678
FID1, FID2, FID3, FID4, FID5, FID6: Fiducial; Fiducial_0.5mm_Mask1mm; Mouser Link N/A
H1, H2: MountingHole; MountingHole_3.2mm_M3; Mouser Link N/A
J1: ASP-134604-01; ASP13460401; Mouser Part Number 200-ASP-134604-01
J2, J3: Conn_01x03_Pin; PinHeader_1x03_P2.54mm_Vertical_SMD_Pin1Left
J10, J11, J12: Conn_02x06_Odd_Even; PinSocket_2x06_P2.54mm_Vertical
JP1, JP2: SolderJumper_2_Open; SolderJumper-2_P1.3mm_Open_TrianglePad1.0x1.5mm; Mouser Link N/A; not fitted
R1: 5k; R_0805_2012Metric_Pad1.20x1.40mm_HandSolder
R2: 1k; R_0805_2012Metric_Pad1.20x1.40mm_HandSolder
U1, U2: SN65LVDS2DBV; SOT-23-5
U3: NCV317; SOT-223-3_TabPin2

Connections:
1V5: C1.1, C2.1, C3.1, R1.1, U3.2 (VO); also elsewhere on the board
3V3: J1.C39, J1.D32, J1.D36, J1.D38, J1.D40, J10.11, J10.12, J11.11, J11.12, J12.11, J12.12, U3.3 (VI); also elsewhere on the board
+12V: J1.C35, J1.C37
/ADC_Circuit/CLK: U1.5 (R); also elsewhere on the board
/ADC_Circuit/PD: J2.2; also elsewhere on the board
/CLK0_M2C_N: J1.H5, U1.4 (B)
/CLK0_M2C_P: J1.H4, U1.3 (A)
/CLK1_M2C_N: J1.G3, J10.1
/CLK1_M2C_P: J1.G2, J10.2
/DAC Circuit/CLKA/CLKIQ: U2.5 (R); also elsewhere on the board
/DAC Circuit/SLEEP: J3.2; also elsewhere on the board
/DP0_C2M_N: J1.C3
/DP0_C2M_P: J1.C2
/DP0_M2C_N: J1.C7
/DP0_M2C_P: J1.C6
/GA0: J1.C34; also elsewhere on the board
/GA1: J1.D35; also elsewhere on the board
/GBTCLK0_M2C_N: J1.D5
/GBTCLK0_M2C_P: J1.D4
/Identification_EEPROM/SCL: JP2.2 (B); also elsewhere on the board
/Identification_EEPROM/SDA: JP1.2 (B); also elsewhere on the board
/LA00_N_CC: J1.G7; also elsewhere on the board
/LA00_P_CC: J1.G6; also elsewhere on the board
/LA01_N: J1.D9, J10.3
/LA01_P: J1.D8, J10.4
/LA02_N: J1.H8; also elsewhere on the board
/LA02_P: J1.H7; also elsewhere on the board
/LA03_N: J1.G10; also elsewhere on the board
/LA03_P: J1.G9; also elsewhere on the board
/LA04_N: J1.H11; also elsewhere on the board
/LA04_P: J1.H10; also elsewhere on the board
/LA05_N: J1.D12, J10.7
/LA05_P: J1.D11, J10.8
/LA06_N: J1.C11, J10.5
/LA06_P: J1.C10, J10.6
/LA07_N: J1.H14; also elsewhere on the board
/LA07_P: J1.H13; also elsewhere on the board
/LA08_N: J1.G13; also elsewhere on the board
/LA08_P: J1.G12; also elsewhere on the board
/LA09_N: J1.D15, J11.1
/LA09_P: J1.D14, J11.2
/LA10_N: J1.C15, J11.3
/LA10_P: J1.C14, J11.4
/LA11_N: J1.H17; also elsewhere on the board
/LA11_P: J1.H16; also elsewhere on the board
/LA12_N: J1.G16; also elsewhere on the board
/LA12_P: J1.G15; also elsewhere on the board
/LA13_N: J1.D18, J11.5
/LA13_P: J1.D17, J11.6
/LA14_N: J1.C19, J11.7
/LA14_P: J1.C18, J11.8
/LA15_N: J1.H20; also elsewhere on the board
/LA15_P: J1.H19; also elsewhere on the board
/LA16_N: J1.G19; also elsewhere on the board
/LA16_P: J1.G18; also elsewhere on the board
/LA17_N_CC: J1.D21, J12.2
/LA17_P_CC: J1.D20, J12.1
/LA18_N_CC: J1.C23, J12.4
/LA18_P_CC: J1.C22, J12.3
/LA19_N: J1.H23; also elsewhere on the board
/LA19_P: J1.H22; also elsewhere on the board
/LA20_N: J1.G22; also elsewhere on the board
/LA20_P: J1.G21; also elsewhere on the board
/LA21_N: J1.H26; also elsewhere on the board
/LA21_P: J1.H25; also elsewhere on the board
/LA22_N: J1.G25; also elsewhere on the board
/LA22_P: J1.G24; also elsewhere on the board
/LA23_N: J1.D24; also elsewhere on the board
/LA23_P: J1.D23; also elsewhere on the board
/LA24_N: J1.H29; also elsewhere on the board
/LA24_P: J1.H28; also elsewhere on the board
/LA25_N: J1.G28; also elsewhere on the board
/LA25_P: J1.G27; also elsewhere on the board
/LA26_N: J1.D27, U2.4 (B)
/LA26_P: J1.D26, U2.3 (A)
/LA27_N: J1.C27, J12.6
/LA27_P: J1.C26, J12.5
/LA28_N: J1.H32; also elsewhere on the board
/LA28_P: J1.H31; also elsewhere on the board
/LA29_N: J1.G31; also elsewhere on the board
/LA29_P: J1.G30; also elsewhere on the board
/LA30_N: J1.H35; also elsewhere on the board
/LA30_P: J1.H34; also elsewhere on the board
/LA31_N: J1.G34; also elsewhere on the board
/LA31_P: J1.G33; also elsewhere on the board
/LA32_N: J1.H38; also elsewhere on the board
/LA32_P: J1.H37; also elsewhere on the board
/LA33_N: J1.G37; also elsewhere on the board
/LA33_P: J1.G36; also elsewhere on the board
/PG_C2M: J1.D1
/SCL: J1.C30, J12.7, JP2.1 (A)
/SDA: J1.C31, J12.8, JP1.1 (A)
/TCK: J1.D29
/TDI: J1.D30, J1.D31
/TMS: J1.D33
/TRST_L: J1.D34
/VREF_A_M2C: J1.H1
GNDA: C1.2, C2.2, C3.2, C37.1, C38.1, J1.C1, J1.C4, J1.C5, J1.C8, J1.C9, J1.C12, J1.C13, J1.C16, J1.C17, J1.C20, J1.C21, J1.C24, J1.C25, J1.C28, J1.C29, J1.C32, J1.C33, J1.C36, J1.C38, J1.C40, J1.D2, J1.D3, J1.D6, J1.D7, J1.D10, J1.D13, J1.D16, J1.D19, J1.D22, J1.D25, J1.D28, J1.D37, J1.D39, J1.G1, J1.G4, J1.G5, J1.G8, J1.G11, J1.G14, J1.G17, J1.G20, J1.G23, J1.G26, J1.G29, J1.G32, J1.G35, J1.G38, J1.G40, J1.H2, J1.H3, J1.H6, J1.H9, J1.H12, J1.H15, J1.H18, J1.H21, J1.H24, J1.H27, J1.H30, J1.H33, J1.H36, J1.H39, J2.1, J3.1, J10.9, J10.10, J11.9, J11.10, J12.9, J12.10, R2.2, U1.2 (GND), U2.2 (GND); also elsewhere on the board
unnamed: R1.2, R2.1, U3.1 (ADJ)
VADJ: C37.2, C38.2, J1.G39, J1.H40, J2.3, J3.3, U1.1 (V_{CC}), U2.1 (V_{CC}); also elsewhere on the board

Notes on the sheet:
OS = HIGH => I & Q in parallel
MODE = HIGH => DA & DB in parallel

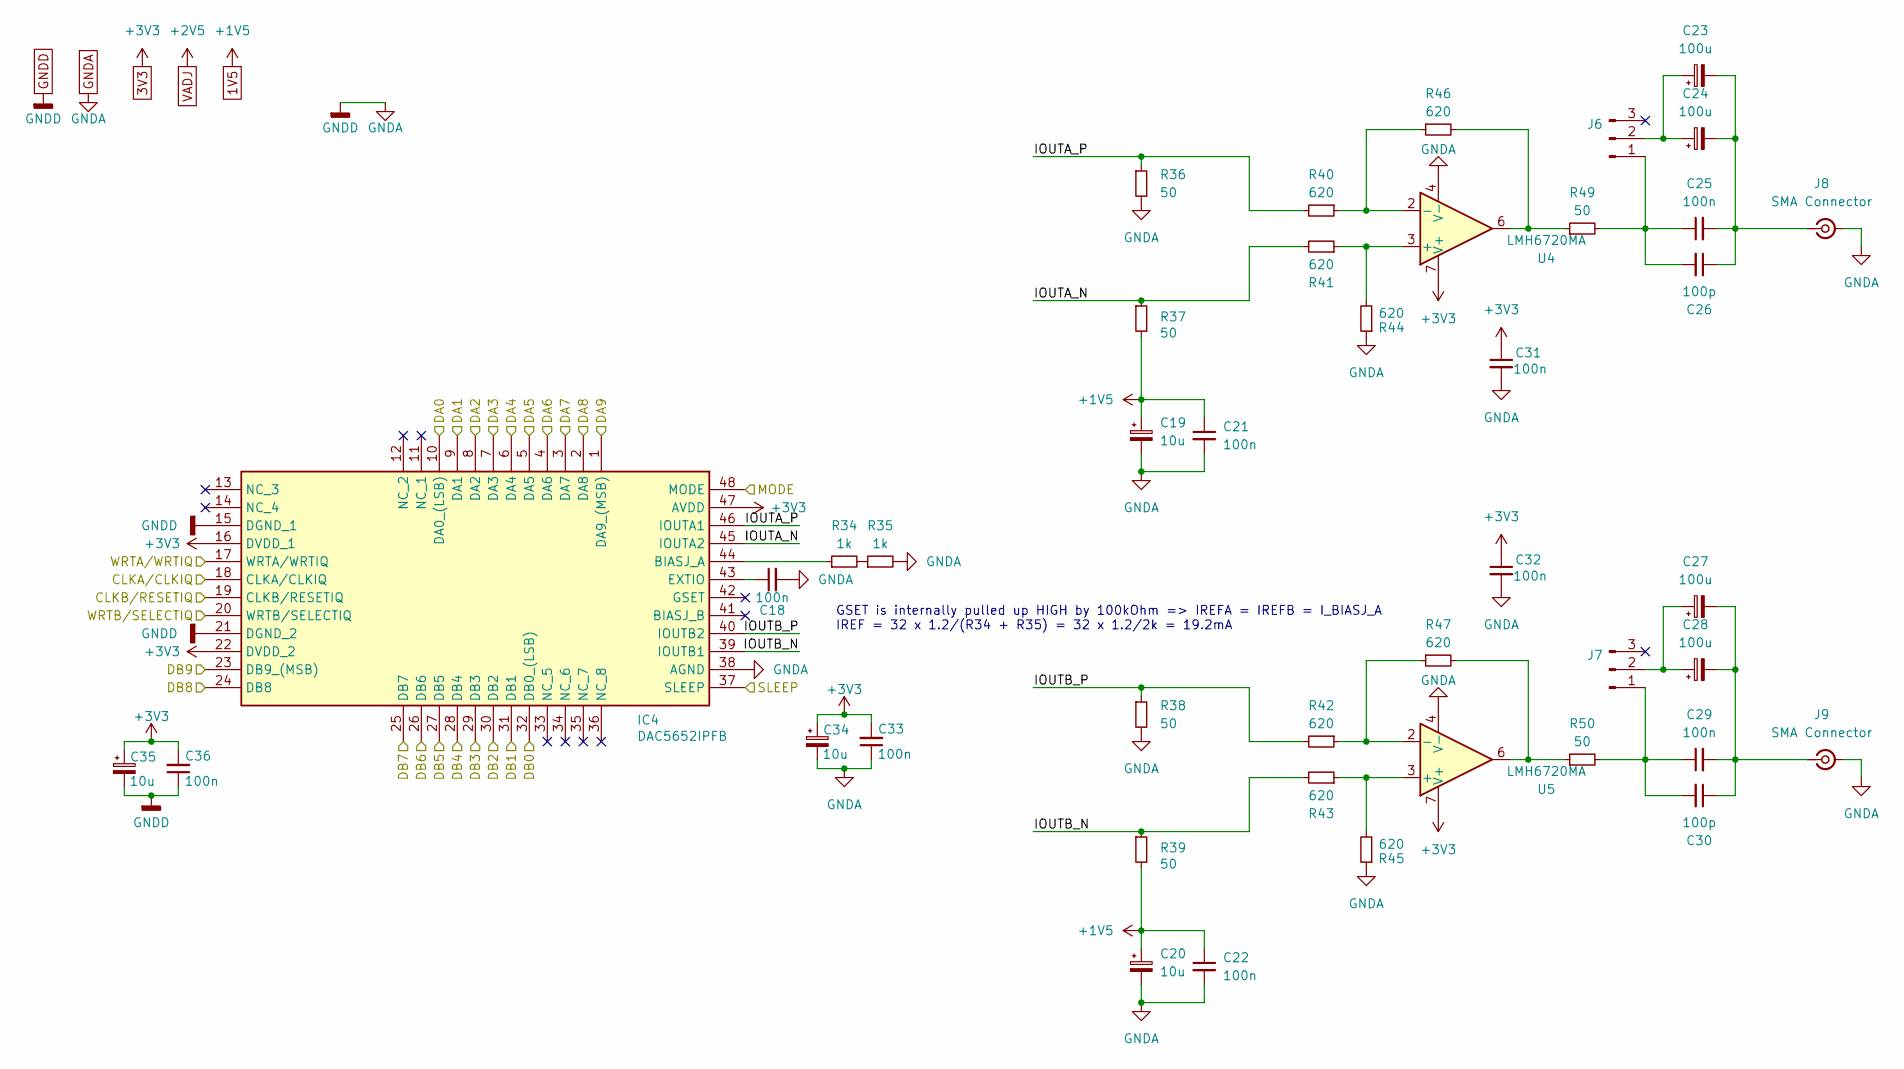
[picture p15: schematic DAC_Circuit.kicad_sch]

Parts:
C18, C21, C22, C25, C29, C31, C32, C33, C36: 100n; C_0805_2012Metric_Pad1.18x1.45mm_HandSolder; LCSC C49678
C19, C20, C34, C35: 10u; C_0805_2012Metric_Pad1.18x1.45mm_HandSolder; LCSC C408141
C23, C24, C27, C28: 100u; CP_Elec_5x5.3; LCSC C15008 (MLCC 1206)
C26, C30: 100p; C_0805_2012Metric_Pad1.18x1.45mm_HandSolder; LCSC C1790
IC4: DAC5652IPFB; TQFP-48_7x7mm_P0.5mm; Mouser Part Number 595-DAC5652IPFB
J6, J7: Conn_01x03_Pin; PinHeader_1x03_P2.54mm_Vertical_SMD_Pin1Left
J8, J9: SMA Connector; SMA_Amphenol_132134_Vertical
R34, R35: 1k; R_0805_2012Metric_Pad1.20x1.40mm_HandSolder
R36, R37, R38, R39, R49, R50: 50; R_0805_2012Metric_Pad1.20x1.40mm_HandSolder
R40, R41, R42, R43, R44, R45, R46, R47: 620; R_0805_2012Metric_Pad1.20x1.40mm_HandSolder
U4, U5: LMH6720MA; SOIC-8_3.9x4.9mm_P1.27mm

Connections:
1V5: C19.1, C20.1, C21.1, C22.1, R37.2, R39.2; also elsewhere on the board
3V3: C31.1, C32.1, C33.2, C34.1, C35.1, C36.2, IC4.16 (DVDD_1), IC4.22 (DVDD_2), IC4.47 (AVDD), U4.7 (V+), U5.7 (V+); also elsewhere on the board
/DAC Circuit/CLKA/CLKIQ: IC4.18 (CLKA/CLKIQ), IC4.19 (CLKB/RESETIQ); also elsewhere on the board
/DAC Circuit/IOUTA_N: IC4.45 (IOUTA2), R37.1, R41.2
/DAC Circuit/IOUTA_P: IC4.46 (IOUTA1), R36.1, R40.2
/DAC Circuit/IOUTB_N: IC4.39 (IOUTB1), R39.1, R43.2
/DAC Circuit/IOUTB_P: IC4.40 (IOUTB2), R38.1, R42.2
/DAC Circuit/SLEEP: IC4.37 (SLEEP); also elsewhere on the board
/LA21_N: IC4.27 (DB5); also elsewhere on the board
/LA21_P: IC4.28 (DB4); also elsewhere on the board
/LA22_N: IC4.29 (DB3); also elsewhere on the board
/LA22_P: IC4.30 (DB2); also elsewhere on the board
/LA23_N: IC4.31 (DB1); also elsewhere on the board
/LA23_P: IC4.32 (DB0_(LSB)); also elsewhere on the board
/LA24_N: IC4.23 (DB9_(MSB)); also elsewhere on the board
/LA24_P: IC4.24 (DB8); also elsewhere on the board
/LA25_N: IC4.25 (DB7); also elsewhere on the board
/LA25_P: IC4.26 (DB6); also elsewhere on the board
/LA28_N: IC4.9 (DA1); also elsewhere on the board
/LA28_P: IC4.10 (DA0_(LSB)); also elsewhere on the board
/LA29_N: IC4.17 (WRTA/WRTIQ); also elsewhere on the board
/LA29_P: IC4.20 (WRTB/SELECTIQ); also elsewhere on the board
/LA30_N: IC4.5 (DA5); also elsewhere on the board
/LA30_P: IC4.6 (DA4); also elsewhere on the board
/LA31_N: IC4.7 (DA3); also elsewhere on the board
/LA31_P: IC4.8 (DA2); also elsewhere on the board
/LA32_N: IC4.1 (DA9_(MSB)); also elsewhere on the board
/LA32_P: IC4.2 (DA8); also elsewhere on the board
/LA33_N: IC4.3 (DA7); also elsewhere on the board
/LA33_P: IC4.4 (DA6); also elsewhere on the board
GNDA: C18.2, C19.2, C20.2, C21.2, C22.2, C31.2, C32.2, C33.1, C34.2, C35.2, C36.1, IC4.15 (DGND_1), IC4.21 (DGND_2), IC4.38 (AGND), J8.2 (Ext), J9.2 (Ext), R35.2, R36.2, R38.2, R44.1, R45.1, U4.4 (V-), U5.4 (V-); also elsewhere on the board
unnamed: IC4.44 (BIASJ_A), R34.1
unnamed: C18.1, IC4.43 (EXTIO)
unnamed: C25.1, C26.2, J6.1, R49.2
unnamed: C23.1, C24.1, J6.2
unnamed: C29.1, C30.2, J7.1, R50.2
unnamed: C27.1, C28.1, J7.2
unnamed: C23.2, C24.2, C25.2, C26.1, J8.1 (In)
unnamed: C27.2, C28.2, C29.2, C30.1, J9.1 (In)
unnamed: R34.2, R35.1
unnamed: R46.2, R49.1, U4.6
unnamed: R47.2, R50.1, U5.6
unnamed: R41.1, R44.2, U4.3 (+)
unnamed: R40.1, R46.1, U4.2 (-)
unnamed: R43.1, R45.2, U5.3 (+)
unnamed: R42.1, R47.1, U5.2 (-)
VADJ: IC4.48 (MODE); also elsewhere on the board

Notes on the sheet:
GSET is internally pulled up HIGH by 100kOhm => IREFA = IREFB = I_BIASJ_A IREF = 32 x 1.2/(R34 + R35) = 32 x 1.2/2k = 19.2mA

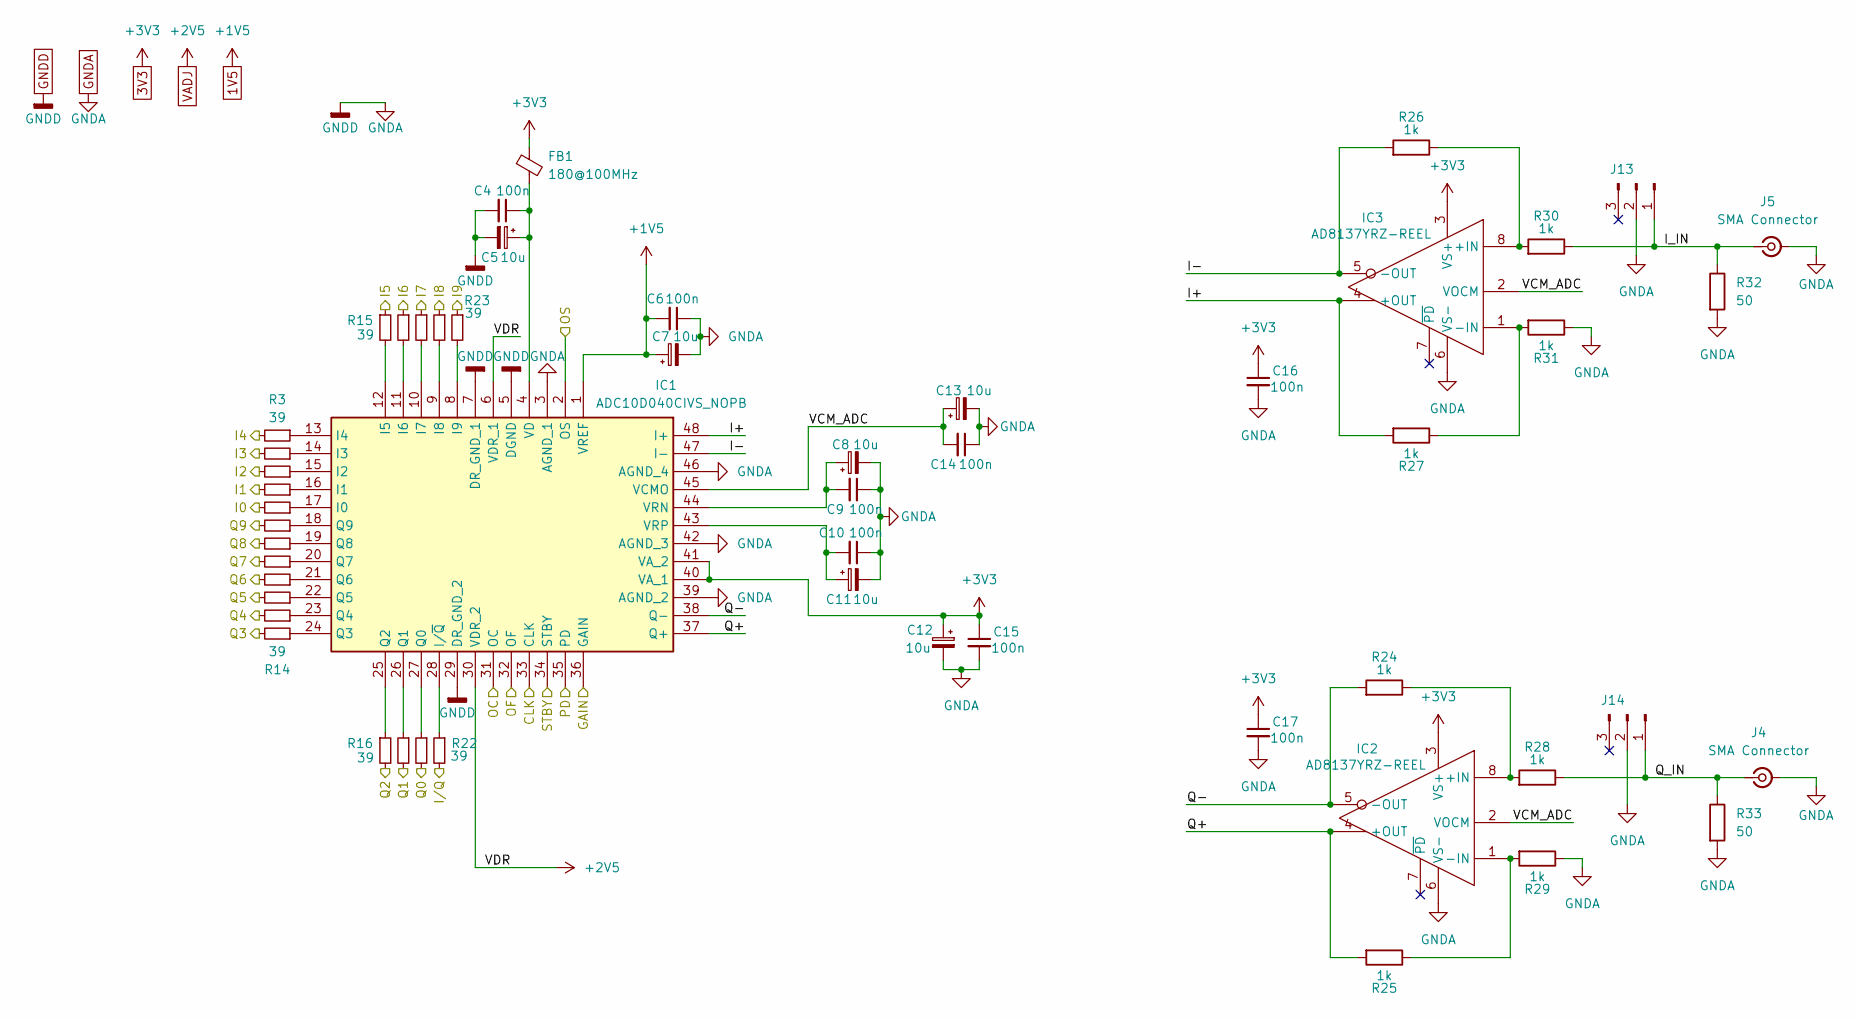
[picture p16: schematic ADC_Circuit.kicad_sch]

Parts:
C4, C6, C9, C10, C14, C15, C16, C17: 100n; C_0805_2012Metric_Pad1.18x1.45mm_HandSolder; LCSC C49678
C5, C7, C8, C11, C12, C13: 10u; C_0805_2012Metric_Pad1.18x1.45mm_HandSolder; LCSC C408141
FB1: 180@100MHz; L_0805_2012Metric_Pad1.15x1.40mm_HandSolder
IC1: ADC10D040CIVS_NOPB; TQFP-48_7x7mm_P0.5mm; Mouser Part Number 926-ADC10D040CIVSNPB
IC2, IC3: AD8137YRZ-REEL; SOIC-8_3.9x4.9mm_P1.27mm; Mouser Part Number 584-AD8137YRZ-R
J4, J5: SMA Connector; SMA_Amphenol_132134_Vertical
J13, J14: Conn_01x03_Pin; PinHeader_1x03_P2.54mm_Vertical_SMD_Pin1Left
R3, R4, R5, R6, R7, R8, R9, R10, R11, R12, R13, R14, R15, R16, R17, R18, R19, R20, R21, R22, R23: 39; R_0805_2012Metric_Pad1.20x1.40mm_HandSolder
R24, R25, R26, R27, R28, R29, R30, R31: 1k; R_0805_2012Metric_Pad1.20x1.40mm_HandSolder
R32, R33: 50; R_0805_2012Metric_Pad1.20x1.40mm_HandSolder

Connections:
1V5: C6.2, C7.1, IC1.1 (VREF); also elsewhere on the board
3V3: C12.1, C15.1, C16.1, C17.1, FB1.1, IC1.40 (VA_1), IC1.41 (VA_2), IC2.3 (VS+), IC3.3 (VS+); also elsewhere on the board
/ADC_Circuit/CLK: IC1.33 (CLK); also elsewhere on the board
/ADC_Circuit/I+: IC1.48 (I+), IC3.4 (+OUT), R27.2
/ADC_Circuit/I-: IC1.47 (I-), IC3.5 (-OUT), R26.2
/ADC_Circuit/I_IN: J5.1 (In), J13.1, R30.1, R32.1
/ADC_Circuit/PD: IC1.34 (STBY), IC1.35 (PD); also elsewhere on the board
/ADC_Circuit/Q+: IC1.37 (Q+), IC2.4 (+OUT), R25.2
/ADC_Circuit/Q-: IC1.38 (Q-), IC2.5 (-OUT), R24.2
/ADC_Circuit/Q_IN: J4.1 (In), J14.1, R28.1, R33.1
/ADC_Circuit/VCM_ADC: C13.1, C14.2, IC1.45 (VCMO), IC2.2 (VOCM), IC3.2 (VOCM)
/LA00_N_CC: IC1.32 (OF); also elsewhere on the board
/LA00_P_CC: IC1.36 (GAIN); also elsewhere on the board
/LA02_N: R22.2; also elsewhere on the board
/LA02_P: IC1.31 (OC); also elsewhere on the board
/LA03_N: R18.2; also elsewhere on the board
/LA03_P: R20.2; also elsewhere on the board
/LA04_N: R14.2; also elsewhere on the board
/LA04_P: R16.2; also elsewhere on the board
/LA07_N: R10.2; also elsewhere on the board
/LA07_P: R11.2; also elsewhere on the board
/LA08_N: R12.2; also elsewhere on the board
/LA08_P: R13.2; also elsewhere on the board
/LA11_N: R6.2; also elsewhere on the board
/LA11_P: R7.2; also elsewhere on the board
/LA12_N: R8.2; also elsewhere on the board
/LA12_P: R9.2; also elsewhere on the board
/LA15_N: R15.1; also elsewhere on the board
/LA15_P: R3.2; also elsewhere on the board
/LA16_N: R4.2; also elsewhere on the board
/LA16_P: R5.2; also elsewhere on the board
/LA19_N: R23.1; also elsewhere on the board
/LA19_P: R21.1; also elsewhere on the board
/LA20_N: R19.1; also elsewhere on the board
/LA20_P: R17.1; also elsewhere on the board
GNDA: C4.2, C5.2, C6.1, C7.2, C8.2, C9.1, C10.1, C11.2, C12.2, C13.2, C14.1, C15.2, C16.2, C17.2, IC1.3 (AGND_1), IC1.5 (DGND), IC1.7 (DR_GND_1), IC1.29 (DR_GND_2), IC1.39 (AGND_2), IC1.42 (AGND_3), IC1.46 (AGND_4), IC2.6 (VS-), IC3.6 (VS-), J4.2 (Ext), J5.2 (Ext), J13.2, J14.2, R29.1, R31.1, R32.2, R33.2; also elsewhere on the board
unnamed: IC1.17 (I0), R7.1
unnamed: IC1.16 (I1), R6.1
unnamed: IC1.15 (I2), R5.1
unnamed: IC1.14 (I3), R4.1
unnamed: IC1.13 (I4), R3.1
unnamed: IC1.12 (I5), R15.2
unnamed: IC1.11 (I6), R17.2
unnamed: IC1.10 (I7), R19.2
unnamed: IC1.9 (I8), R21.2
unnamed: IC1.8 (I9), R23.2
unnamed: IC1.28 (I/~Q), R22.1
unnamed: IC1.27 (Q0), R20.1
unnamed: IC1.26 (Q1), R18.1
unnamed: IC1.25 (Q2), R16.1
unnamed: IC1.24 (Q3), R14.1
unnamed: IC1.23 (Q4), R13.1
unnamed: IC1.22 (Q5), R12.1
unnamed: IC1.21 (Q6), R11.1
unnamed: IC1.20 (Q7), R10.1
unnamed: IC1.19 (Q8), R9.1
unnamed: IC1.18 (Q9), R8.1
unnamed: C4.1, C5.1, FB1.2, IC1.4 (VD)
unnamed: C8.1, C9.2, IC1.44 (VRN)
unnamed: C10.2, C11.1, IC1.43 (VRP)
unnamed: IC2.8 (+IN), R24.1, R28.2
unnamed: IC2.1 (-IN), R25.1, R29.2
unnamed: IC3.8 (+IN), R26.1, R30.2
unnamed: IC3.1 (-IN), R27.1, R31.2
VADJ: IC1.2 (OS), IC1.6 (VDR_1), IC1.30 (VDR_2); also elsewhere on the board

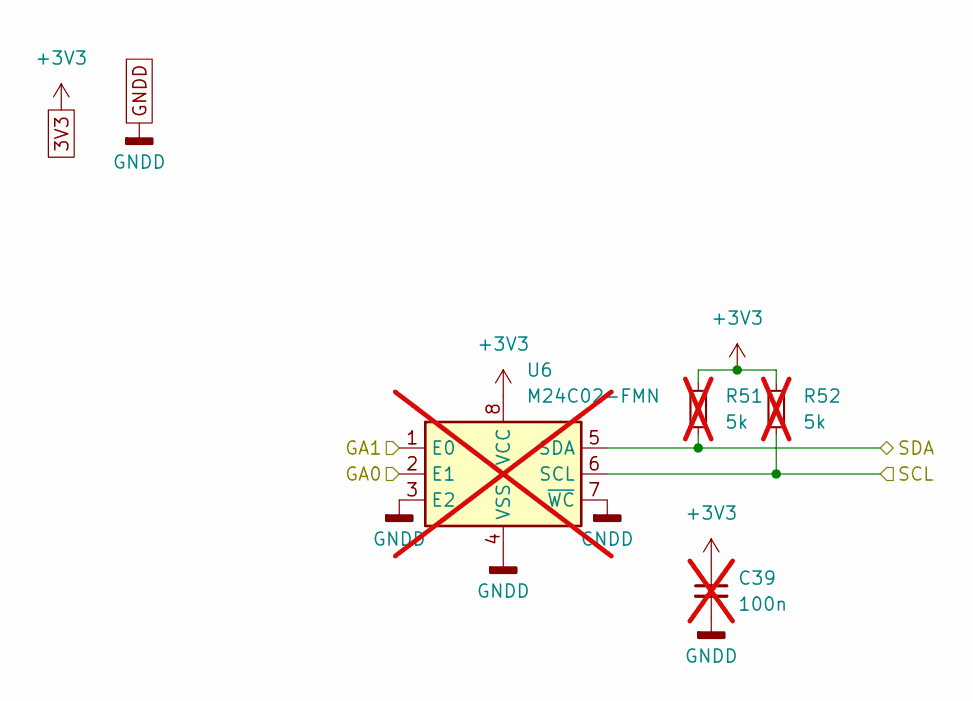
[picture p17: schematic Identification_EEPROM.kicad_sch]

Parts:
C39: 100n; C_0805_2012Metric_Pad1.18x1.45mm_HandSolder; not fitted
R51, R52: 5k; R_0805_2012Metric_Pad1.20x1.40mm_HandSolder; not fitted
U6: M24C02-FMN; SOIC-8_3.9x4.9mm_P1.27mm; not fitted

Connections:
3V3: C39.1, R51.1, R52.1, U6.8 (VCC); also elsewhere on the board
/GA0: U6.2 (E1); also elsewhere on the board
/GA1: U6.1 (E0); also elsewhere on the board
/Identification_EEPROM/SCL: R52.2, U6.6 (SCL); also elsewhere on the board
/Identification_EEPROM/SDA: R51.2, U6.5 (SDA); also elsewhere on the board
GNDA: C39.2, U6.3 (E2), U6.4 (VSS), U6.7 (~WC); also elsewhere on the board

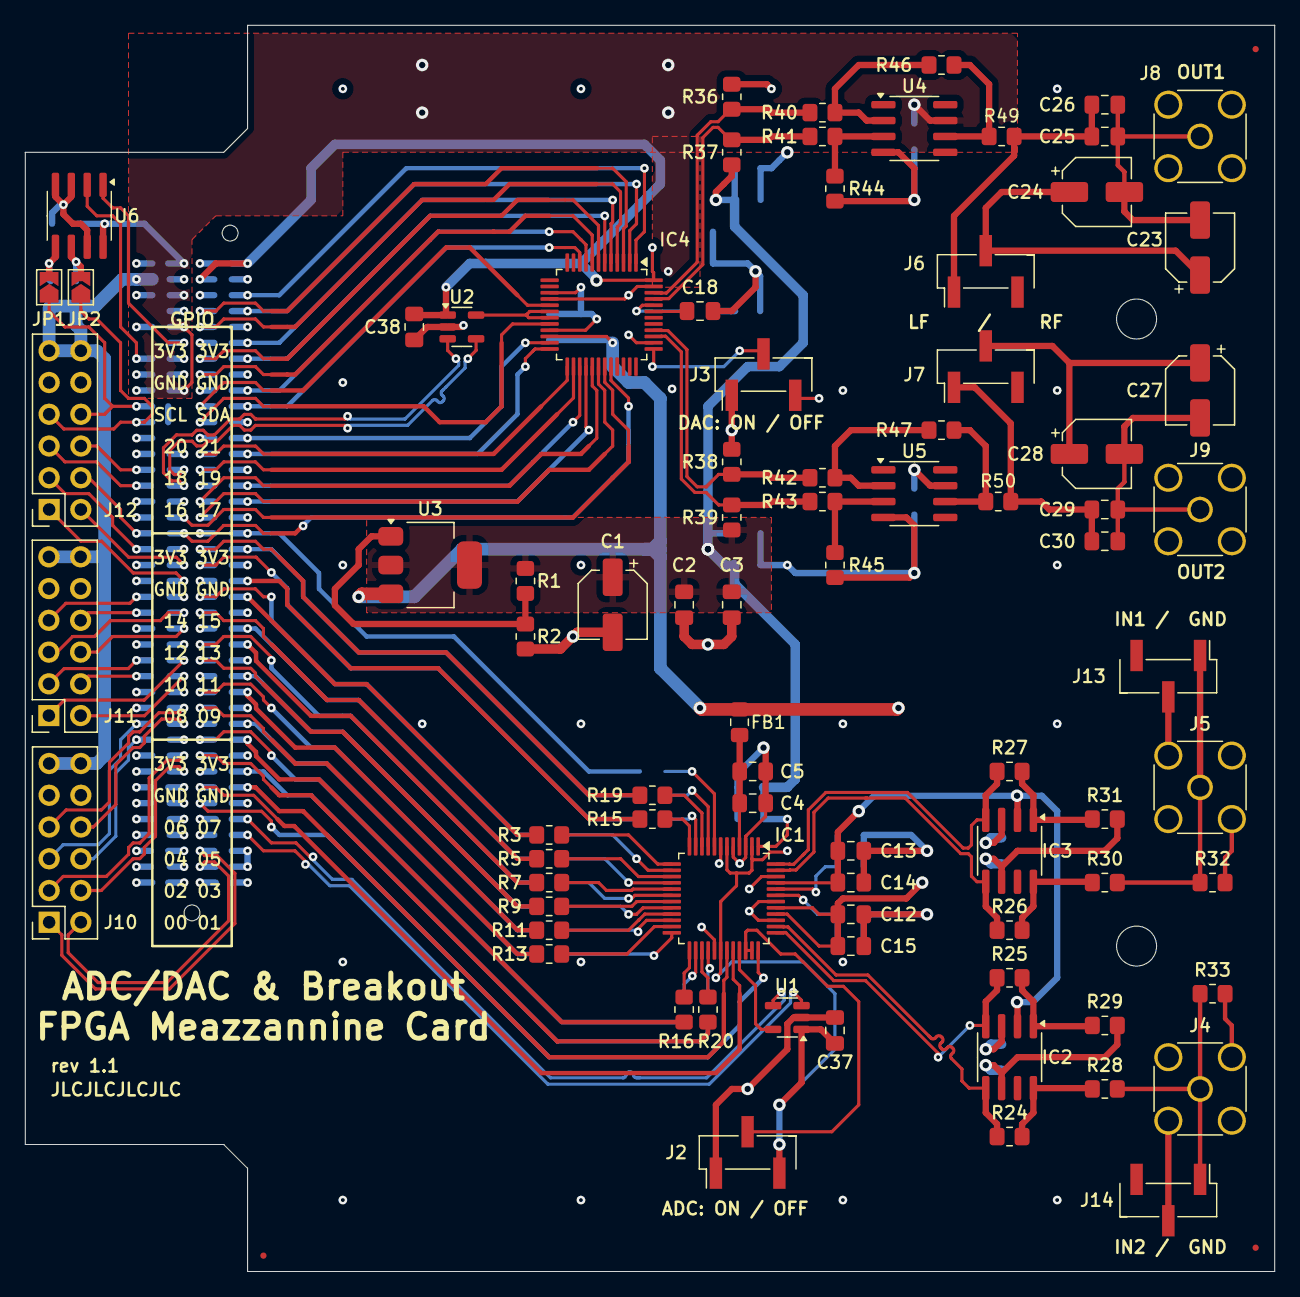
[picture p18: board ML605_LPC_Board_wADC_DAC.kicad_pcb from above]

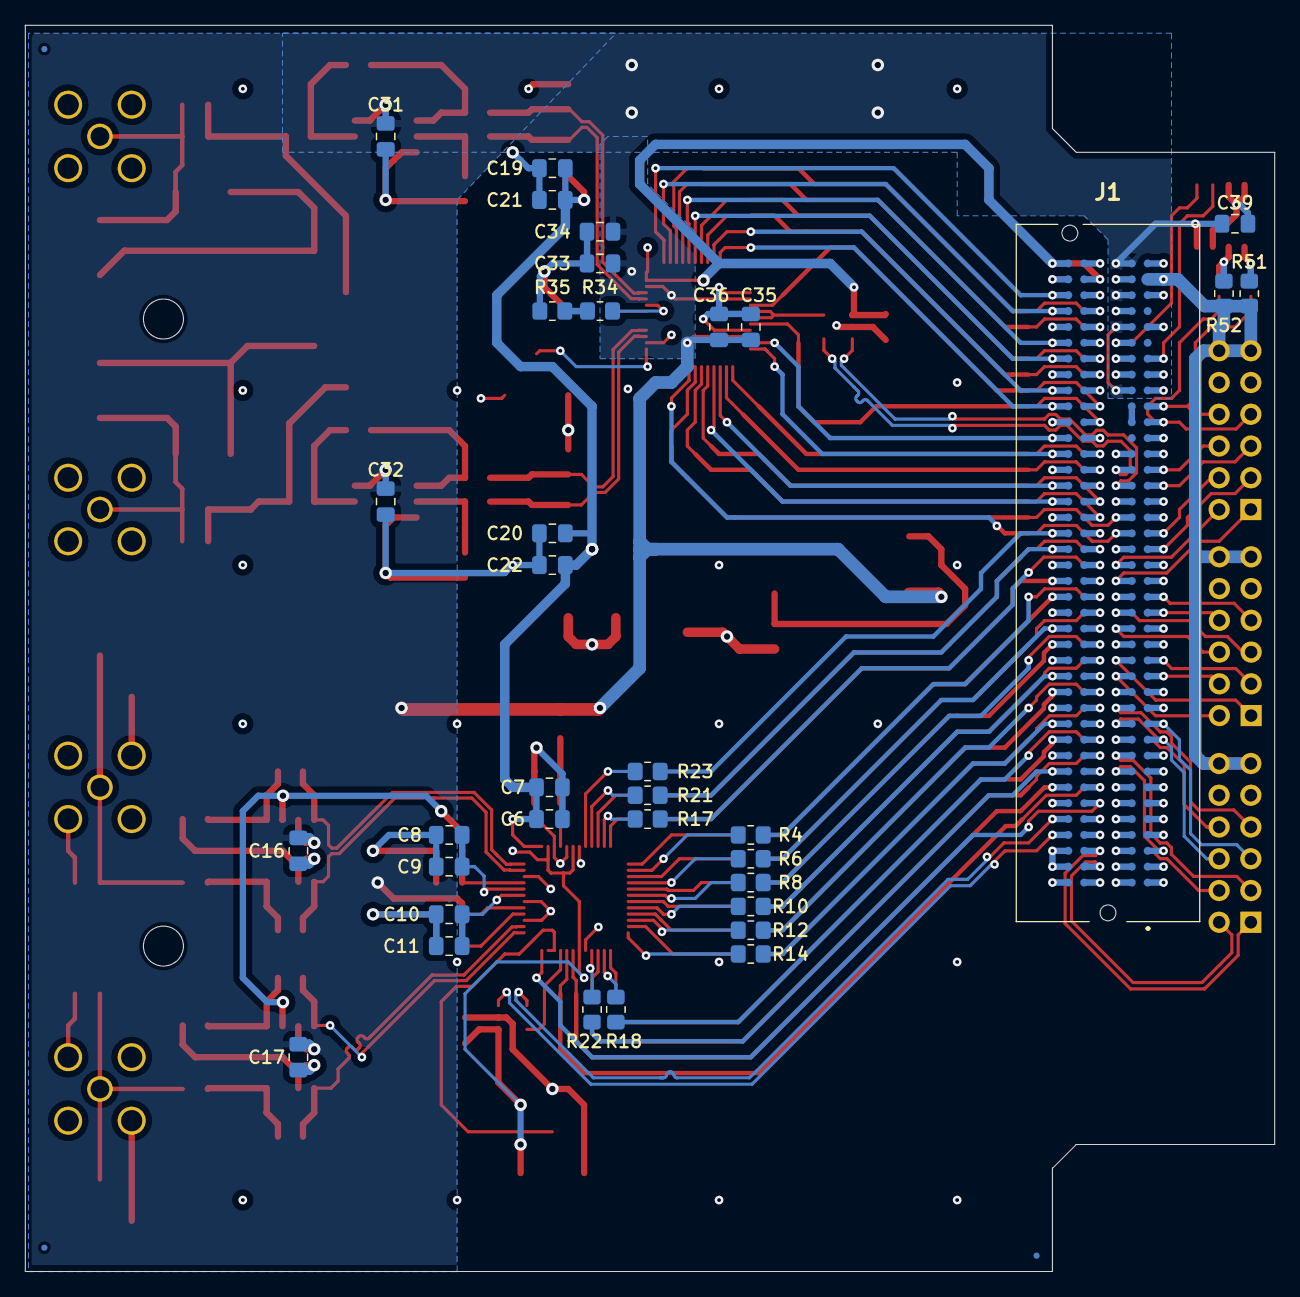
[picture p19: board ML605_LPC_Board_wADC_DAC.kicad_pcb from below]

Board: 4 copper layers, 99.9 x 99.7 mm, 125 parts (38 on the bottom side), 143 nets.

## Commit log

2024-08-25 First Commit - 70% done
    [ADC_Circuit.kicad_sch, DAC_Circuit.kicad_sch, ML605_LPC_Board_wADC_DAC.kicad_pcb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]
2024-08-26 Second commit, routed digital data inputs of DAC
    Now I have problems routing the WRTA & WRTB pins of the DAC. Will probably have to reassign some pins of the digital data inputs (potential solution: I could make the WRTA/WRTB pair be situated at LA29, and the DAC_DB input pins would have to be cascaded down. DAC_DB1/DAC_DB0 would then have to be moved to the other side of the LPC connector, probably where WRTA/WRTB are now, at LA26). It'll look weird in the pinout diagram, but at least it'll work (hopefully :@ )
    [ML605_LPC_Board_wADC_DAC.kicad_pcb, ML605_LPC_Board_wADC_DAC.kicad_sch, VITA 57.4 LPC_ADCDAC_Pinout.xlsx]
2024-08-26 The ADC/DAC part of the board is done
    Now I just need to figure out how to do the GPIO breakout, but I have a lot more flexibility here. Ideally, I'd like to keep the PMOD connector format, however I'm not sure if that is going to be possible. If I can't do that due to routing issues, than I can probably just stick a 50-something pin header on the the top side of the board at the left edge, on the other side of the LPC connector and call it a day.
    [ML605_LPC_Board_wADC_DAC.kicad_pcb, ML605_LPC_Board_wADC_DAC.kicad_sch, VITA 57.4 LPC_ADCDAC_Pinout.xlsx]
2024-08-26 Routing is done
    Routing is finally done! Now I just need to add some silkscreen markings, maybe a label, order number placement, and I need to place some ground stitching vias here and there
    [ML605_LPC_Board_wADC_DAC.kicad_pcb, ML605_LPC_Board_wADC_DAC.kicad_sch]
2024-08-26 Minor tracing mistakes fixed
    [ML605_LPC_Board_wADC_DAC.kicad_pcb]
2024-08-26 Other minor changes
    Including removing some unused nets in the schematic, changing L01_P/N back to L01_P/N_CC and adding the Mouser link to the BRD_PRSNT pullup resistor.
    [ML605_LPC_Board_wADC_DAC.kicad_pcb, ML605_LPC_Board_wADC_DAC.kicad_sch, VITA 57.4 LPC_ADCDAC_Pinout.xlsx]
2024-08-29 Added some silkscreen markings
    [ML605_LPC_Board_wADC_DAC.kicad_pcb]
2024-08-29 Changed the VADJ vias to be 0.3mm/0.6mm
    [ML605_LPC_Board_wADC_DAC.kicad_pcb]
2024-08-29 Added GND stitching vias and fiducial markings
    [ADC_Circuit.kicad_sch, DAC_Circuit.kicad_sch, ML605_LPC_Board_wADC_DAC.kicad_pcb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]
2024-08-30 Changed all via sizes to comply with the 0.2mm annular ring constraint
    And fixed some other issues regarding clearance constraints
    [ADC_Circuit.kicad_sch, DAC_Circuit.kicad_sch, ML605_LPC_Board_wADC_DAC.kicad_pcb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]
2024-08-30 Fixed some minor silkscreen issues, added a missing capacitor connection
    [ML605_LPC_Board_wADC_DAC.kicad_pcb]
2024-08-30 Added fiducials on the back side of the PCB
    [ML605_LPC_Board_wADC_DAC-B_Cu.gbr, ML605_LPC_Board_wADC_DAC-B_Mask.gbr, ML605_LPC_Board_wADC_DAC-B_Silks.gbr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]
2024-08-30 Moved J1 silkscreen reference designator
    [ML605_LPC_Board_wADC_DAC.kicad_pcb]
2024-08-30 New gerbers
    [ML605_LPC_Board_wADC_DAC-B_Cu.gbr, ML605_LPC_Board_wADC_DAC-B_Mask.gbr, ML605_LPC_Board_wADC_DAC-B_Silks.gbr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]
2024-08-30 Increased trace width of ADC differential amplifier bypass capacitors
    [ML605_LPC_Board_wADC_DAC-B_Cu.gbr, ML605_LPC_Board_wADC_DAC-B_Mask.gbr, ML605_LPC_Board_wADC_DAC-B_Silks.gbr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]
2024-08-30 Moved a grounding via
    [ML605_LPC_Board_wADC_DAC-B_Cu.gbr, ML605_LPC_Board_wADC_DAC-B_Mask.gbr, ML605_LPC_Board_wADC_DAC-B_Silks.gbr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]
2024-08-30 Swapped INx / GND silkscreen markings in the ADC selection jumpers
    [ML605_LPC_Board_wADC_DAC-B_Cu.gbr, ML605_LPC_Board_wADC_DAC-B_Mask.gbr, ML605_LPC_Board_wADC_DAC-B_Silks.gbr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]
2024-08-30 Thickened a GND trace for J10
    [ML605_LPC_Board_wADC_DAC-B_Cu.gbr, ML605_LPC_Board_wADC_DAC-B_Mask.gbr, ML605_LPC_Board_wADC_DAC-B_Silks.gbr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]
2024-08-30 Added BOM
    [BOM_ML605_LPC_Board_wADC_DAC.csv, ML605_LPC_Board_wADC_DAC.kicad_sch]
2024-08-30 Did some length matching for the ADC clock differential pair
    [ML605_LPC_Board_wADC_DAC-B_Cu.gbr, ML605_LPC_Board_wADC_DAC-B_Mask.gbr, ML605_LPC_Board_wADC_DAC-B_Silks.gbr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]
2024-08-31 Review photos and Mezzaninne spelling mistake fixed
    [DAC_Circuit.kicad_sch, ML605_LPC_Board_wADC_DAC.kicad_pcb, VITA 57.4 LPC_ADCDAC_Pinout.xlsx]
2024-08-31 Error in schematic, DAC output opamp is LMH6720, not LMH6702
    [DAC_Circuit.kicad_sch, ML605_LPC_Board_wADC_DAC.kicad_pcb]
2024-08-31 Rev 1.1
    Multiple changes are made, as per suggestions made by the redditors of r/PrintedCircuitBoards. Firstly, two 50 ohm resistors were added in series with the DAC output in order to comply with the minimum peak output current of the op-amps of 50mA. Secondly, two M3 mounting holes were added in order to have the possibility to add standoffs. Thirdly, a clearance issue regarding jumpers near the LPC connector on the ML602 board was fixed by changing the board geometry to include a cutout for these.
    Some other things to look into are the use of some ferrite beads for supplies of the analog ICs.
    [DAC_Circuit.kicad_sch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]
2024-08-31 Updated BOM
    [BOM_ML605_LPC_Board_wADC_DAC.csv, BOM_ML605_LPC_Board_wADC_DAC.xlsx]
2024-08-31 Reduced horizontal board dimension a bit
    [ML605_LPC_Board_wADC_DAC-B_Cu.gbr, ML605_LPC_Board_wADC_DAC-B_Mask.gbr, ML605_LPC_Board_wADC_DAC-B_Silks.gbr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]
2024-08-31 Removed some 90 internal bends in the board outline for aesthetic purposes
    [ML605_LPC_Board_wADC_DAC-B_Cu.gbr, ML605_LPC_Board_wADC_DAC-B_Mask.gbr, ML605_LPC_Board_wADC_DAC-B_Silks.gbr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]
2024-08-31 Fixed pcb dimensions (again)
    [ML605_LPC_Board_wADC_DAC-B_Cu.gbr, ML605_LPC_Board_wADC_DAC-B_Mask.gbr, ML605_LPC_Board_wADC_DAC-B_Silks.gbr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]
2024-09-01 Added identification EEPROM to comply with the 2019 revision of the VITA 57.1 standard
    The EEPROM and its complementary components are marked as DNP, as they are not necessary for the ML602 board to function
    [Identification_EEPROM.kicad_sch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]
2024-09-01 Changed clock comparators to dedicated LVDS decoders and changed ADC Vdd inductor to ferrite bead
    [ADC_Circuit.kicad_sch, BOM_ML605_LPC_Board_wADC_DAC.xlsx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]
2024-09-01 Tied PRSNT pin directly to ground without resistor, fixed reference of J1
    [ML605_LPC_Board_wADC_DAC-B_Cu.gbr, ML605_LPC_Board_wADC_DAC-B_Mask.gbr, ML605_LPC_Board_wADC_DAC-B_Silks.gbr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]
2024-09-03 Rev 1.1 final version
    [ML605_LPC_Board_wADC_DAC.kicad_pcb]
